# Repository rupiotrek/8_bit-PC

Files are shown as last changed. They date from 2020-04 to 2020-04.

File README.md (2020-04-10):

# 8_bit-PC

Project based on the project of [8 bit PC by Ben Eater](https://eater.net/8bit/ "8 bit by Ben Eater").  

# Version 1

Contains:
1. 3 board & schematic designs
2. Gerber files for production
3. BOM 

Board divided into 3 parts:

## Left

|Name of unit|Description|
| --- | ---|
|**Clock**|Creats clock signal for the board. Can be used also as debugger - clock signal can be made by user |
|**Memory address (MAR)**|Choose from which address PC reads. In *Prog*  mode user can specify address to which instructions in RAM module will be written |
|**RAM**| Contains instructions for specified memory address. In *Prog* mode user can specify instruction for chosen in MAR module addres |
|**Instruction register (IR)**| Decides which step of the program will be made next. It is sent to PC module. Also sends the address to read from  |
|**Control Word (CW)**| Operates whole PC. Also shows which flag is ON during working|

## Middle
|Name of unit|Description|
| ----- |-----|
|**Display module**|Shows current information on the bus |
|**Sorting module**|Unit transports signals from left and right board to specified unit|

## Right
|Name of unit|Description|
|-----|-----|
|**Program counter (PC)**|Makes steps for the PC. Can also change them because of *jump* function |
|**Power**| Main power unit. Contains overvoltage and reverse polarity protection |
|**A register**|Register that can read from and write informations for the bus. Contains information on which computer is working recently |
|**Arithmetic Logic Unit (ALU)**| Mathematical unit. Operates on variables from A and B registers. Module can add and substruct them |
|**B register**|Register that can read informations from the bus. Contains information on which computer is working recently  |
|**Output register**| Show the variable on 4 display LED. Unit has two modes: non-neagtive and negative  |

# Links

This materials were really helpful during creation:

+ [Tutorial how to build the 8 bit PC](https://www.youtube.com/watch?v=HyznrdDSSGM&list=PLowKtXNTBypGqImE405J2565dvjafglHU)
+ [Ben Eater project site](https://eater.net/8bit/ )
+ [Helpful list of 74ls series ](https://www.futurlec.com/IC74LS00Series.shtml)

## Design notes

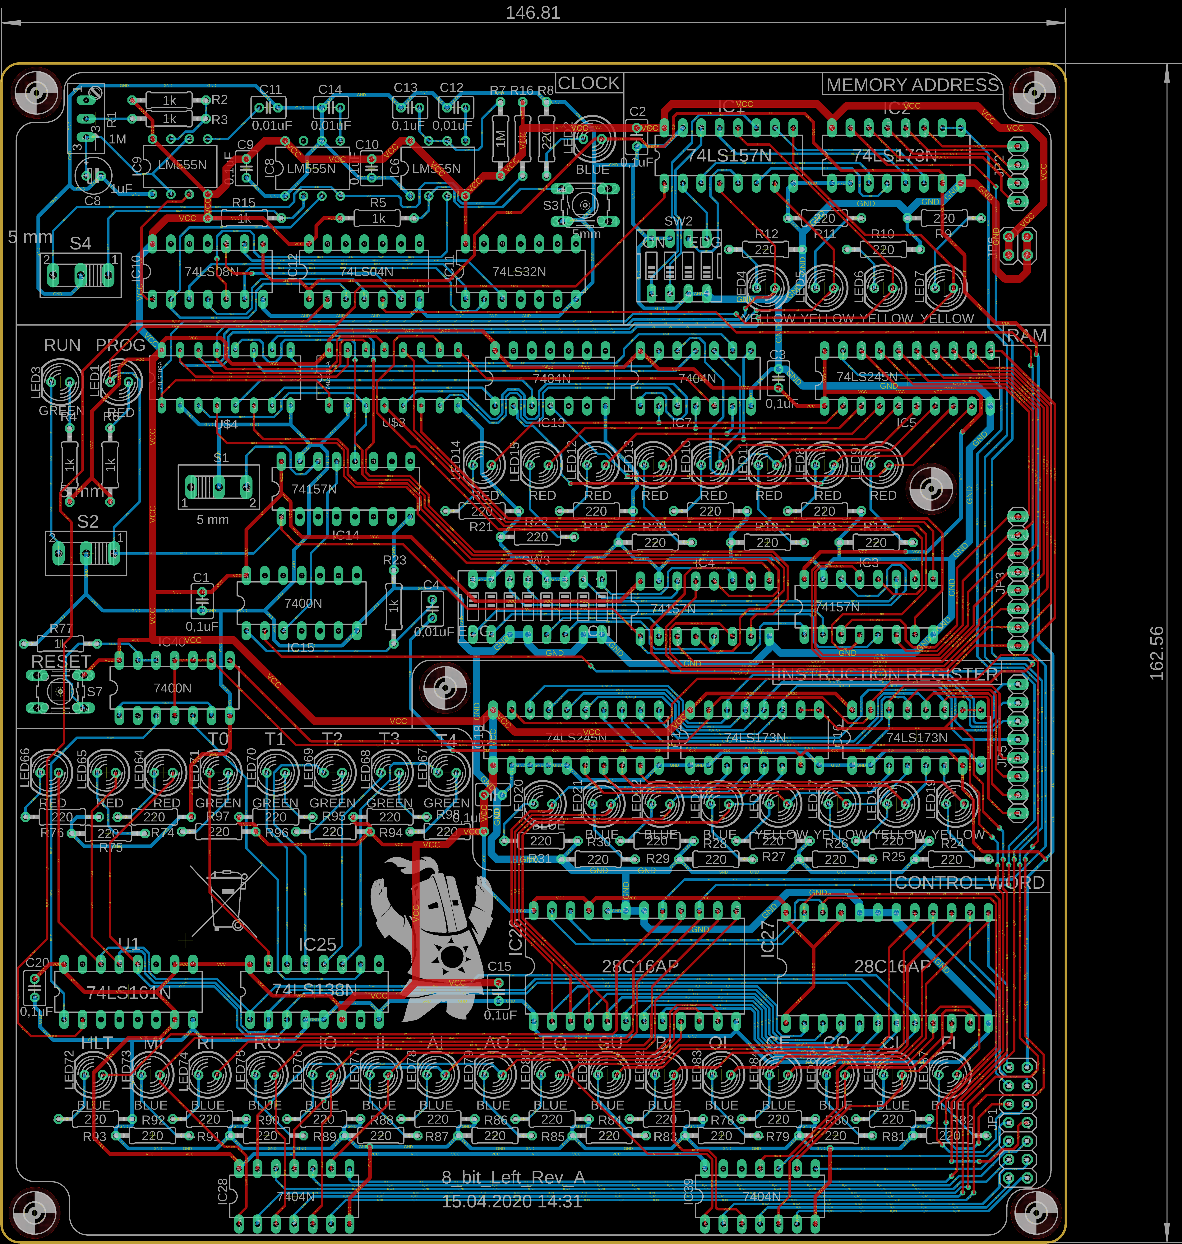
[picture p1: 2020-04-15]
Version_1/Screen_Left.png

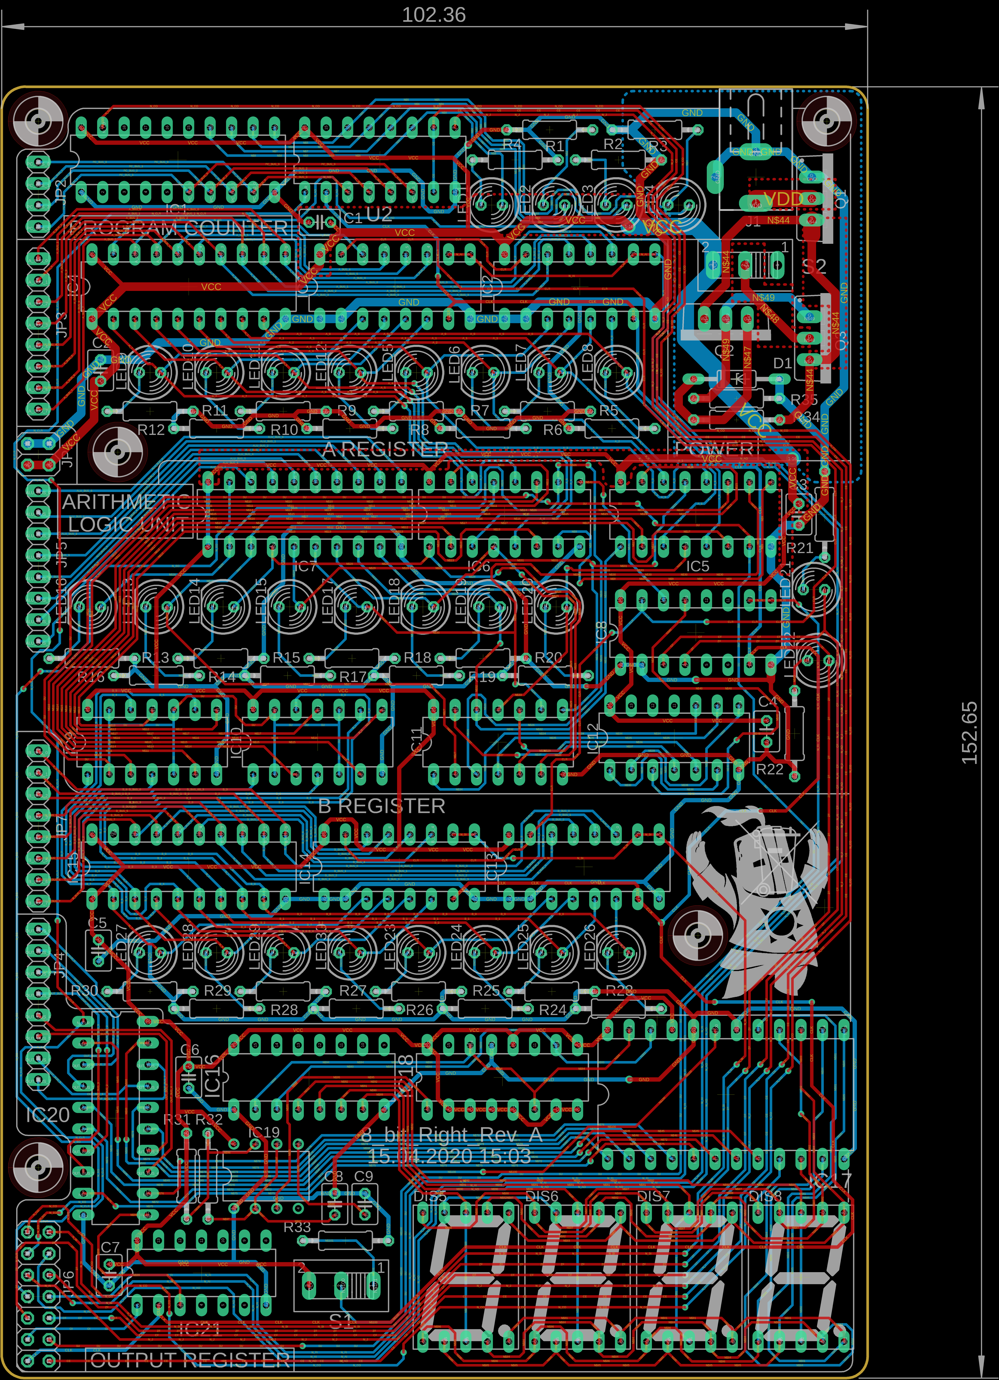
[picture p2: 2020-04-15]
Version_1/Screen_Right.png

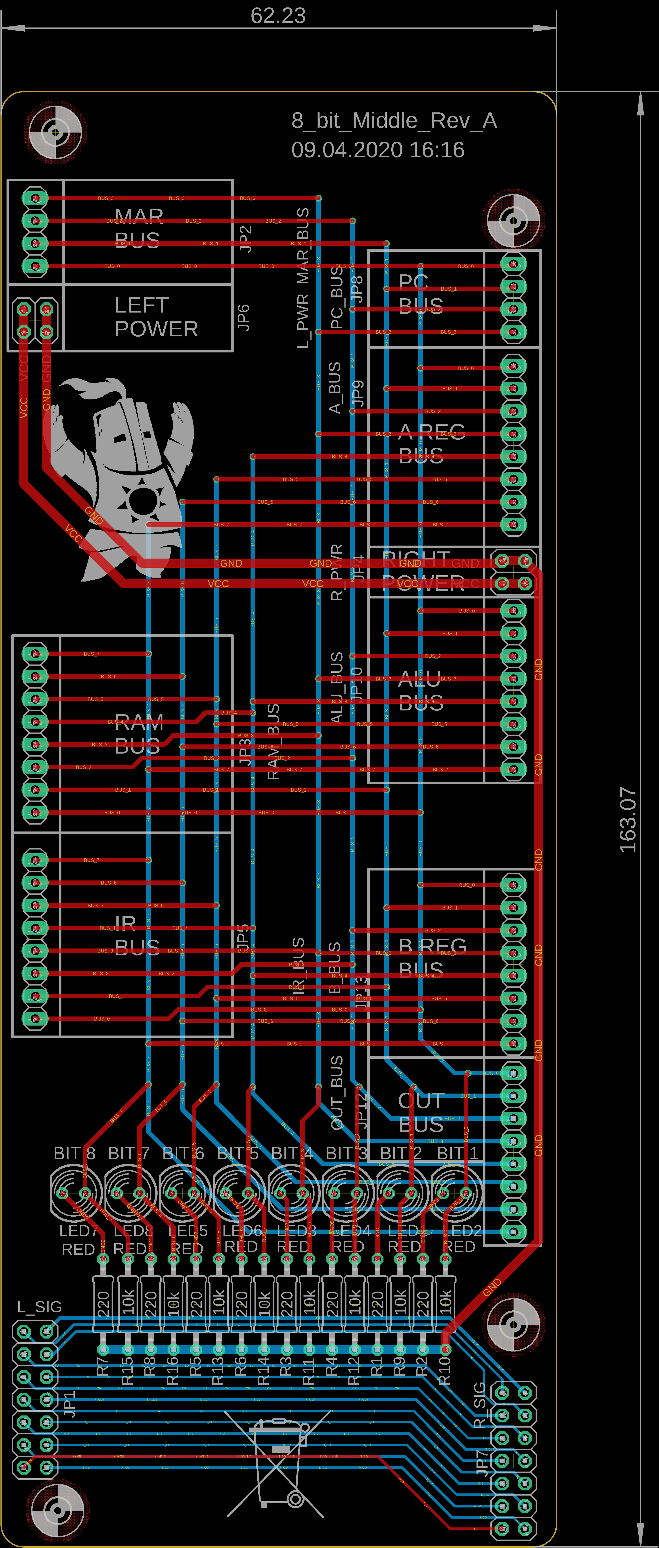
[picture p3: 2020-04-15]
Version_1/Screen_Middle.png

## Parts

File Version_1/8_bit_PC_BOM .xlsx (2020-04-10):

Qty | Value | Device | PCB | Package | Parts | Description | MF | MPN | OC_FARNELL | OC_NEWARK | POPULARITY | R9 | SPICEPREFIX
1 | 5mm | 10-XX | Left | B3F-10XX | S3 | OMRON SWITCH |  | B3F-1000 | 176432 | 36M3542 | 72
1 | RESET | 10-XX | Left | B3F-10XX | S7 | OMRON SWITCH |  | B3F-1000 | 176432 | 36M3542 | 72
3 | 5 mm | 255SB | Left | 255SB | S1, S2, S4 | SLIDING SWITCH |  |  |  |  | 11
1 |  | 255SB | Right | 255SB | S2 | SLIDING SWITCH |  |  |  |  | 11
1 | 5 mm | 255SB | Right | 255SB | S1 | SLIDING SWITCH |  |  |  |  | 11
2 | 28C16AP | 28C16AP | Left | DIL24-6 | IC26, IC27 | CMOS EPROM 16 K (2 K x 8) |  | CAT28C16ALI-12 | 1718292 | 06R0648
1 | 28C16AP | 28C16AP | Right | DIL24-6 | IC17 | CMOS EPROM 16 K (2 K x 8) |  | CAT28C16ALI-12 | 1718292 | 06R0648
2 | 74LS00N | 74LS00N | Left | DIL14 | IC15, IC40 | Quad 2-input NAND gate |  |  |  |  | 0
1 | 74LS02N | 74LS02N | Right | DIL14 | IC11 | Quad 2-input NOR gate |  |  |  |  | 0
4 | 74LS04N | 74LS04N | Left | DIL14 | IC7, IC13, IC28, IC39 | Hex INVERTER |  |  |  |  | 0
1 | 74LS04N | 74LS04N | Left | DIL14 | IC12 | Hex INVERTER |  |  |  |  | 0
1 | 74LS08N | 74LS08N | Left | DIL14 | IC10 | Quad 2-input AND gate |  |  |  |  | 0
1 | 74LS08N | 74LS08N | Right | DIL14 | IC21 | Quad 2-input AND gate
1 | 74LS08N | 74LS08N | Right | DIL14 | IC12 | Quad 2-input AND gate |  |  |  |  | 0
1 | 74LS138N | 74LS138N | Left | DIL16 | IC25 | 3-line to 8-line DECODER/DEMULTIPLEXER
1 | 74LS139N | 74LS139N | Right | DIL16 | IC16 | Dual 2-line to 4-line DECODER/DEMULTIPLEXER
3 | 74LS157N | 74LS157N | Left | DIL16 | IC3, IC4, IC14 | Quadruple 2-line to 1-line data SELECTOR/MULTIPLEXER |  |  |  |  | 0
1 | 74LS157N | 74LS157N | Left | DIL16 | IC1 | Quadruple 2-line to 1-line data SELECTOR/MULTIPLEXER
1 | 74LS161N | 74LS161N | Left | DIL16 | U1 | Synchronous 4-bit COUNTER with direct clear
1 | 74LS161N | 74LS161N | Right | DIL16 | U2 | Synchronous 4-bit COUNTER with direct clear
2 | 74LS173N | 74LS173N | Left | DIL16 | IC16, IC17 | 4-bit D type REGISTER, 3-state |  |  |  |  | 0
1 | 74LS173N | 74LS173N | Left | DIL16 | IC2 | 4-bit D type REGISTER, 3-state
5 | 74LS173N | 74LS173N | Right | DIL16 | IC2, IC3, IC8, IC13, IC14 | 4-bit D type REGISTER, 3-state |  |  |  |  | 0
2 | 74LS189A | 74LS189A | Left | 74LS189 | U$3, U$4
2 | 74LS245N | 74LS245N | Left | DIL20 | IC5, IC18 | Octal BUS TRANSCEIVER, 3-state |  |  |  |  | 0
4 | 74LS245N | 74LS245N | Right | DIL20 | IC1, IC4, IC7, IC15 | Octal BUS TRANSCEIVER, 3-state |  |  |  |  | 0
1 | 74LS273N | 74LS273N | Right | DIL20 | IC20 | Octal D type FLIP FLOP, clear
1 | 74LS32N | 74LS32N | Left | DIL14 | IC11 | Quad 2-input OR gate |  |  |  |  | 0
1 | 74LS76N | 74LS76N | Right | DIL16 | IC18 | Dual J-K FLIP FLOP, preset and clear
2 | 74LS86N | 74LS86N | Right | DIL14 | IC9, IC10 | Quad 2-input EXCLUSIVE-OR (XOR) gate |  |  |  |  | 0
2 | 74S283N | 74S283N | Right | DIL16 | IC5, IC6 | 4-bit binary FULL ADDER, fast carry |  |  |  |  | 0
1 | BZX55 | BZX55 | Right | DO35Z10 | D1 | Z DIODE |  |  |  |  | 2
4 | 0,01uF | C-EU025-030X050 | Left | C025-030X050 | C4, C11, C12, C14 | CAPACITOR, European symbol |  |  |  |  |  |  | C
9 | 0,1uF | C-EU025-030X050 | Left | C025-030X050 | C1, C2, C3, C5, C9, C10, C13, C15, C20 | CAPACITOR, European symbol |  |  |  |  |  |  | C
2 | 0,01uF | C-EU025-030X050 | Right | C025-030X050 | C8, C9 | CAPACITOR, European symbol |  |  |  |  |  |  | C
7 | 0,1uF | C-EU025-030X050 | Right | C025-030X050 | C1, C2, C3, C4, C5, C6, C7 | CAPACITOR, European symbol |  |  |  |  |  |  | C
1 | 1uF | CPOL-EUE2-5 | Left | E2-5 | C8 | POLARIZED CAPACITOR, European symbol |  |  |  |  |  |  | C
1 |  | DCJ0303 | Right | DCJ0303 | J1 | DC POWER JACK |  |  | unknown | unknown | 20
4 | HD-H103 | HD-H103 | Right | HDSP-M | DIS5, DIS6, DIS7, DIS8 | LED DISPLAY |  |  | unknown | unknown
3 | IRF9530 | IRF9530 | Right | TO220BV | Q1, Q2, Q3 | P-CHANNEL HEXFET POWER-MOS-FET |  |  |  |  | 4
21 | BLUE | LED5MM | Left | LED5MM | LED2, LED20, LED21, LED22, LED23, LED72, LED73, LED74, LED75, LED76, LED77, LED78, LED79, LED80, LED81, LED82, LED83, LED84, LED85, LED86, LED87 | LED
6 | GREEN | LED5MM | Left | LED5MM | LED3, LED67, LED68, LED69, LED70, LED71 | LED
12 | RED | LED5MM | Left | LED5MM | LED1, LED8, LED9, LED10, LED11, LED12, LED13, LED14, LED15, LED64, LED65, LED66 | LED
8 | YELLOW | LED5MM | Left | LED5MM | LED4, LED5, LED6, LED7, LED16, LED17, LED18, LED19 | LED
8 | RED | LED5MM | Middle | LED5MM | LED1, LED2, LED3, LED4, LED5, LED6, LED7, LED8 | LED
6 | GREEN | LED5MM | Right | LED5MM | LED1, LED2, LED3, LED4, LED21, LED22 | LED
24 | RED | LED5MM | Right | LED5MM | LED5, LED6, LED7, LED8, LED9, LED10, LED11, LED12, LED13, LED14, LED15, LED16, LED17, LED18, LED19, LED20, LED23, LED24, LED25, LED26, LED27, LED28, LED29, LED30 | LED
3 | LM555N | LM555N | Left | DIL08 | IC6, IC8, IC9 | TIMER
1 | LM555N | LM555N | Right | DIL08 | IC19 | TIMER
4 | MOUNT-HOLE2.8 | MOUNT-HOLE2.8 | Middle | 2.8 | H1, H2, H3, H4 | MOUNTING HOLE with drill center marker |  |  |  |  | 15
5 | MOUNT-HOLE2.8 | MOUNT-HOLE2.8 | Right | 2.8 | H1, H2, H3, H5, H6 | MOUNTING HOLE with drill center marker |  |  |  |  | 15
1 |  | PINHD-1X4 | Left | 1X04 | JP2 | PIN HEADER |  |  |  |  | 91
1 | MAR_BUS | PINHD-1X4 | Middle | 1X04 | JP2 | PIN HEADER |  |  |  |  | 91
1 | PC_BUS | PINHD-1X4 | Middle | 1X04 | JP8 | PIN HEADER |  |  |  |  | 91
1 |  | PINHD-1X4 | Right | 1X04 | JP2 | PIN HEADER |  |  |  |  | 91
2 |  | PINHD-1X8 | Left | 1X08 | JP3, JP5 | PIN HEADER |  |  |  |  | 67
1 | ALU_BUS | PINHD-1X8 | Middle | 1X08 | JP10 | PIN HEADER |  |  |  |  | 67
1 | A_BUS | PINHD-1X8 | Middle | 1X08 | JP9 | PIN HEADER |  |  |  |  | 67
1 | B_BUS | PINHD-1X8 | Middle | 1X08 | JP13 | PIN HEADER |  |  |  |  | 67
1 | IR_BUS | PINHD-1X8 | Middle | 1X08 | JP5 | PIN HEADER |  |  |  |  | 67
1 | OUT_BUS | PINHD-1X8 | Middle | 1X08 | JP12 | PIN HEADER |  |  |  |  | 67
1 | RAM_BUS | PINHD-1X8 | Middle | 1X08 | JP3 | PIN HEADER |  |  |  |  | 67
4 |  | PINHD-1X8 | Right | 1X08 | JP3, JP4, JP5, JP7 | PIN HEADER |  |  |  |  | 67
1 |  | PINHD-2X2 | Left | 2X02 | JP6 | PIN HEADER |  |  |  |  | 0
1 | L_PWR | PINHD-2X2 | Middle | 2X02 | JP6 | PIN HEADER |  |  |  |  | 0
1 | R_PWR | PINHD-2X2 | Middle | 2X02 | JP4 | PIN HEADER |  |  |  |  | 0
1 |  | PINHD-2X2 | Right | 2X02 | JP1 | PIN HEADER |  |  |  |  | 0
1 |  | PINHD-2X7 | Left | 2X07 | JP1 | PIN HEADER |  |  |  |  | 8
1 | L_SIG | PINHD-2X7 | Middle | 2X07 | JP1 | PIN HEADER |  |  |  |  | 8
1 | R_SIG | PINHD-2X7 | Middle | 2X07 | JP7 | PIN HEADER |  |  |  |  | 8
1 |  | PINHD-2X7 | Right | 2X07 | JP6 | PIN HEADER |  |  |  |  | 8
1 | 1M | POTTRS64W | Left | S64W | R1 | POTENTIOMETER |  |  |  |  |  | 1M
1 | 1M | R-EU_0207/10 | Left | 0207/10 | R7 | RESISTOR, European symbol |  |  |  |  | 81 |  | R
9 | 1k | R-EU_0207/10 | Left | 0207/10 | R2, R3, R4, R5, R6, R8, R15, R23, R77 | RESISTOR, European symbol |  |  |  |  | 81 |  | R
45 | 220 | R-EU_0207/10 | Left | 0207/10 | R9, R10, R11, R12, R13, R14, R16, R17, R18, R19, R20, R21, R22, R24, R25, R26, R27, R28, R29, R30, R31, R74, R75, R76, R78, R79, R80, R81, R82, R83, R84, R85, R86, R87, R88, R89, R90, R91, R92, R93, R94, R95, R96, R97, R98 | RESISTOR, European symbol |  |  |  |  | 81 |  | R
8 | 10k | R-EU_0207/10 | Middle | 0207/10 | R9, R10, R11, R12, R13, R14, R15, R16 | RESISTOR, European symbol |  |  |  |  | 81 |  | R
8 | 220 | R-EU_0207/10 | Middle | 0207/10 | R1, R2, R3, R4, R5, R6, R7, R8 | RESISTOR, European symbol |  |  |  |  | 81 |  | R
1 | 100k | R-EU_0207/10 | Right | 0207/10 | R32 | RESISTOR, European symbol |  |  |  |  | 81 |  | R
1 | 10k | R-EU_0207/10 | Right | 0207/10 | R33 | RESISTOR, European symbol |  |  |  |  | 81 |  | R
2 | 1k | R-EU_0207/10 | Right | 0207/10 | R31, R35 | RESISTOR, European symbol |  |  |  |  | 81 |  | R
31 | 220 | R-EU_0207/10 | Right | 0207/10 | R1, R2, R3, R4, R5, R6, R7, R8, R9, R10, R11, R12, R13, R14, R15, R16, R17, R18, R19, R20, R21, R22, R23, R24, R25, R26, R27, R28, R29, R30, R34 | RESISTOR, European symbol |  |  |  |  | 81 |  | R
1 |  | SW_DIP-4 | Left | EDG-04 | SW2 | DIP SWITCH
1 |  | SW_DIP-8 | Left | EDG-08 | SW3 | DIP SWITCH |  |  |  |  | 5

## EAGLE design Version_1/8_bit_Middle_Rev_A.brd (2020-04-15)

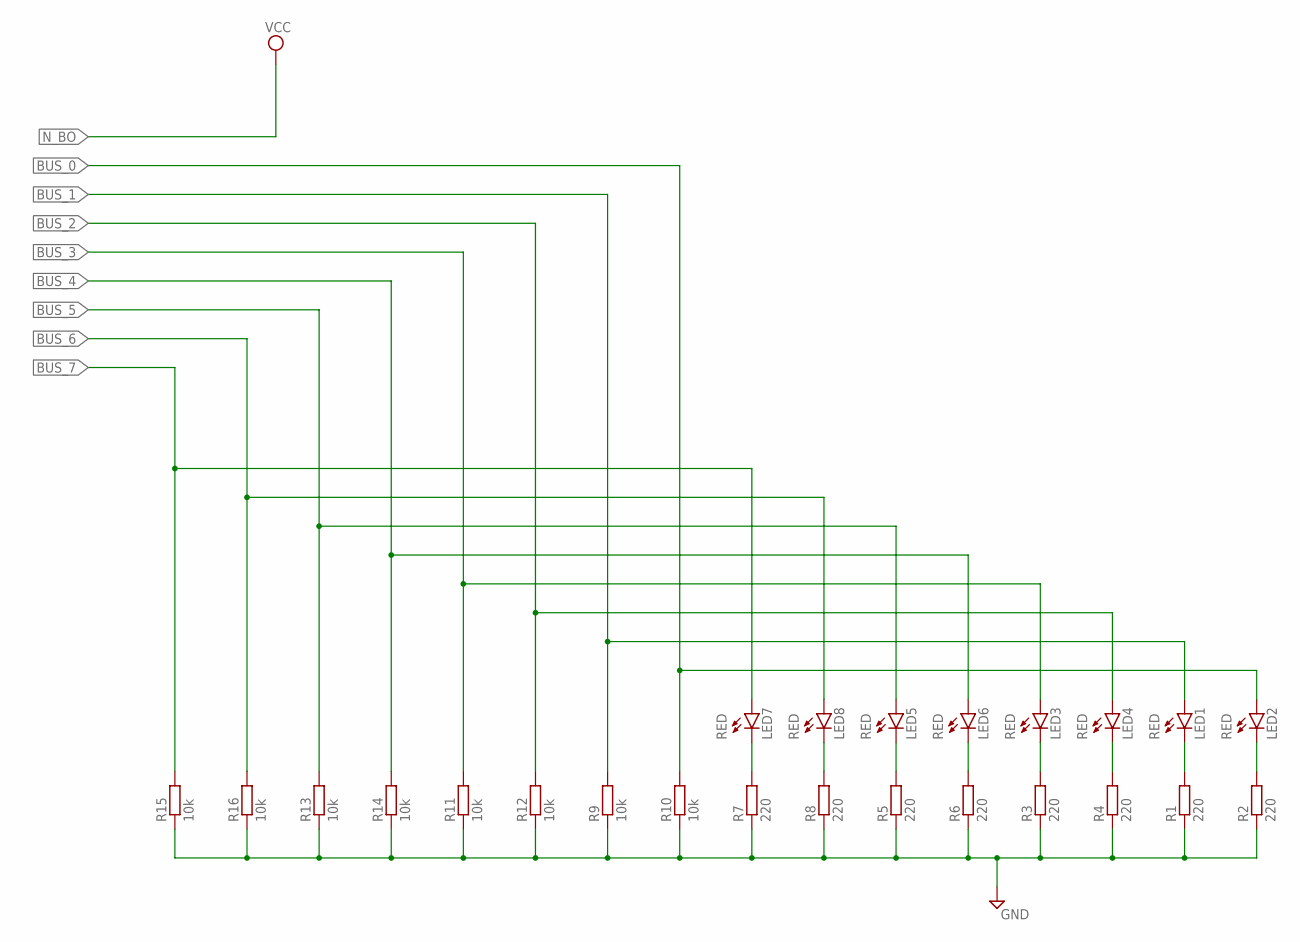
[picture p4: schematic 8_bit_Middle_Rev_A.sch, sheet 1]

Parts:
LED1, LED2, LED3, LED4, LED5, LED6, LED7, LED8: RED; LED5MM
R1, R2, R3, R4, R5, R6, R7, R8: 220; 0207/10
R9, R10, R11, R12, R13, R14, R15, R16: 10k; 0207/10

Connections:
BUS_0: LED2.A, R10.2; also elsewhere on the board
BUS_1: LED1.A, R9.2; also elsewhere on the board
BUS_2: LED4.A, R12.2; also elsewhere on the board
BUS_3: LED3.A, R11.2; also elsewhere on the board
BUS_4: LED6.A, R14.2; also elsewhere on the board
BUS_5: LED5.A, R13.2; also elsewhere on the board
BUS_6: LED8.A, R16.2; also elsewhere on the board
BUS_7: LED7.A, R15.2; also elsewhere on the board
GND: R1.1, R2.1, R3.1, R4.1, R5.1, R6.1, R7.1, R8.1, R9.1, R10.1, R11.1, R12.1, R13.1, R14.1, R15.1, R16.1; also elsewhere on the board
GND1: LED1.K (C), R1.2
GND2: LED2.K (C), R2.2
GND3: LED3.K (C), R3.2
GND5: LED4.K (C), R4.2
GND7: LED5.K (C), R5.2
GND8: LED6.K (C), R6.2
GND9: LED7.K (C), R7.2
GND10: LED8.K (C), R8.2

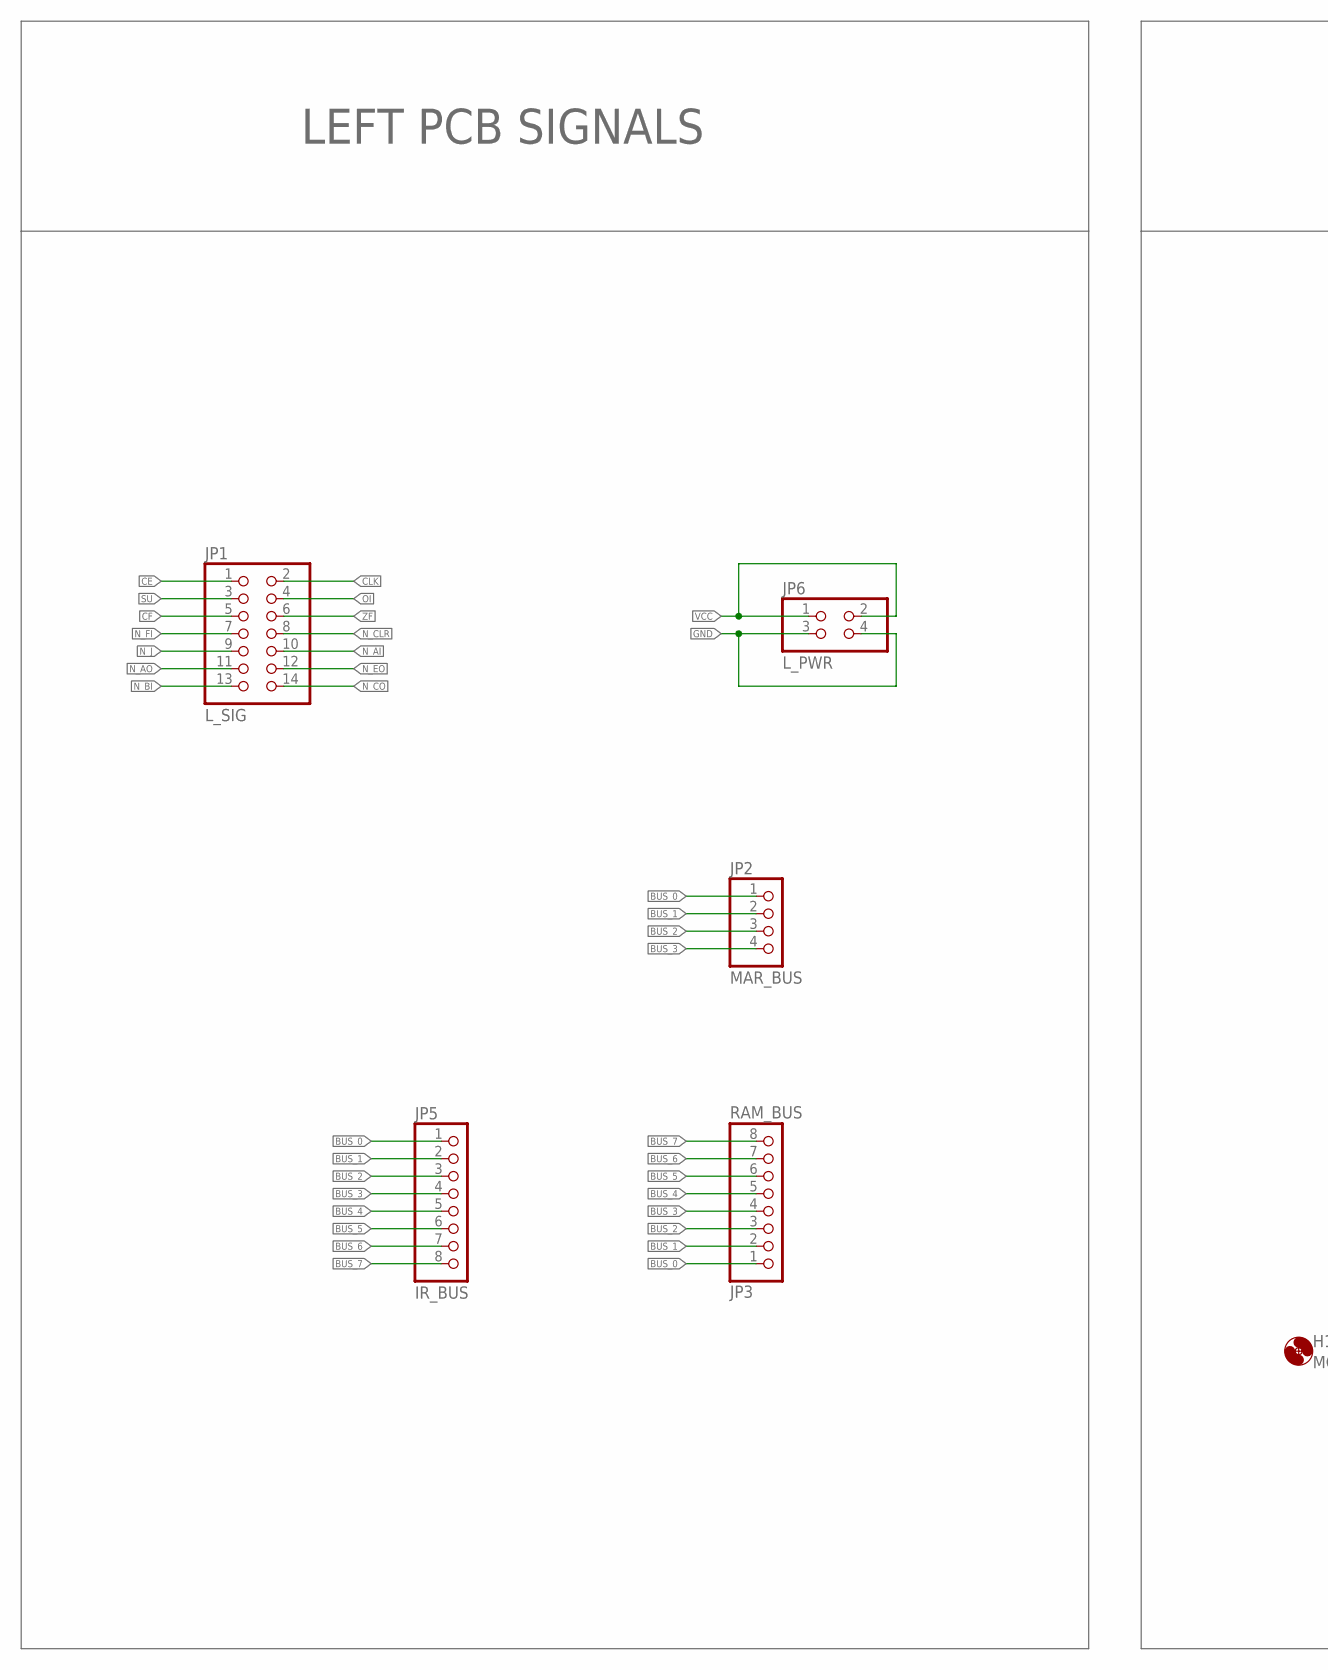
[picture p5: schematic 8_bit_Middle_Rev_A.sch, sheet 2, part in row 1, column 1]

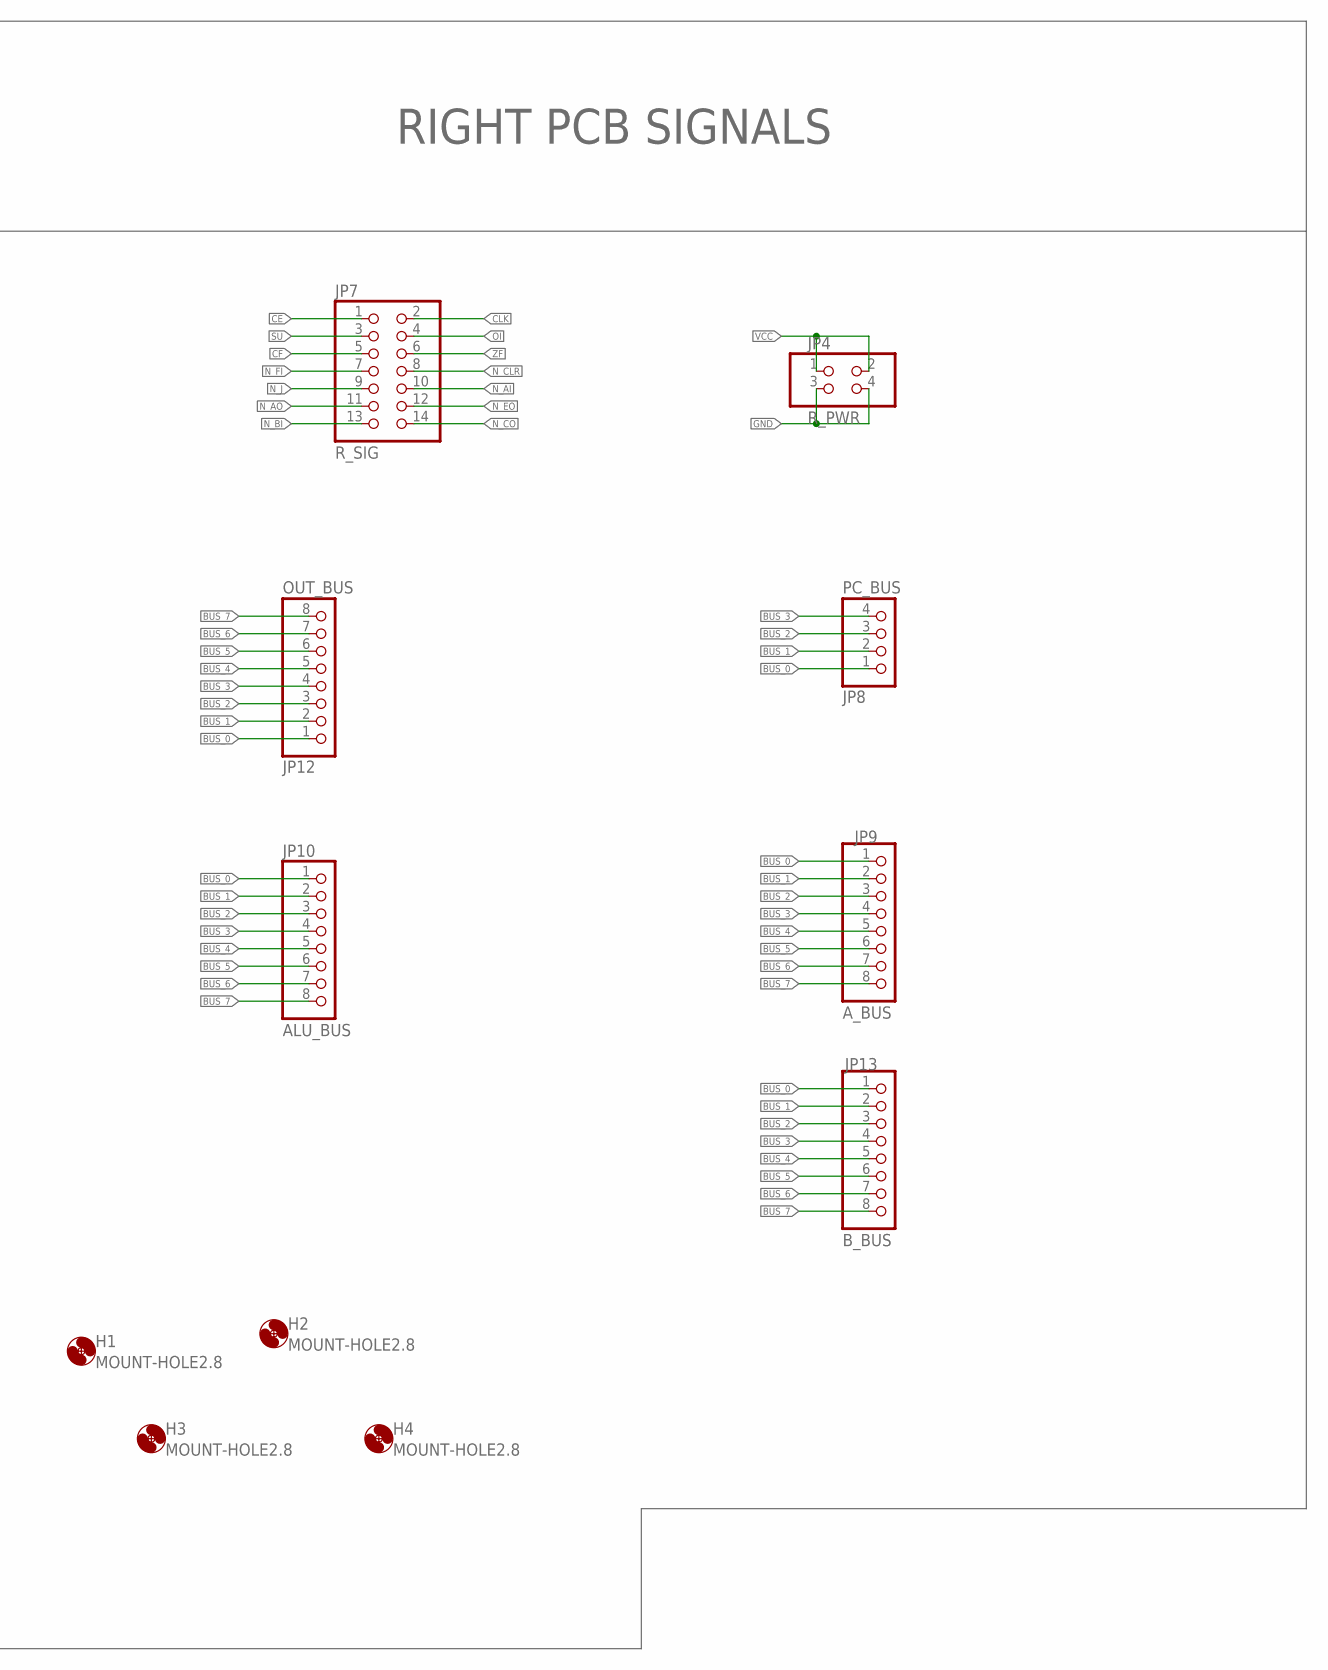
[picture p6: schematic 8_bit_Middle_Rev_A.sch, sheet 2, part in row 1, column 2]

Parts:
H1, H2, H3, H4: MOUNT-HOLE2.8; 2,8
JP1: L_SIG; 2X07
JP2: MAR_BUS; 1X04
JP3: RAM_BUS; 1X08
JP4: R_PWR; 2X02
JP5: IR_BUS; 1X08
JP6: L_PWR; 2X02
JP7: R_SIG; 2X07
JP8: PC_BUS; 1X04
JP9: A_BUS; 1X08
JP10: ALU_BUS; 1X08
JP12: OUT_BUS; 1X08
JP13: B_BUS; 1X08

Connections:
BUS_0: JP2.1, JP3.1, JP5.1, JP8.1, JP9.1, JP10.1, JP12.1, JP13.1; also elsewhere on the board
BUS_1: JP2.2, JP3.2, JP5.2, JP8.2, JP9.2, JP10.2, JP12.2, JP13.2; also elsewhere on the board
BUS_2: JP2.3, JP3.3, JP5.3, JP8.3, JP9.3, JP10.3, JP12.3, JP13.3; also elsewhere on the board
BUS_3: JP2.4, JP3.4, JP5.4, JP8.4, JP9.4, JP10.4, JP12.4, JP13.4; also elsewhere on the board
BUS_4: JP3.5, JP5.5, JP9.5, JP10.5, JP12.5, JP13.5; also elsewhere on the board
BUS_5: JP3.6, JP5.6, JP9.6, JP10.6, JP12.6, JP13.6; also elsewhere on the board
BUS_6: JP3.7, JP5.7, JP9.7, JP10.7, JP12.7, JP13.7; also elsewhere on the board
BUS_7: JP3.8, JP5.8, JP9.8, JP10.8, JP12.8, JP13.8; also elsewhere on the board
CE: JP1.1, JP7.1
CF: JP1.5, JP7.5
CLK: JP1.2, JP7.2
GND: JP4.3, JP4.4, JP6.3, JP6.4; also elsewhere on the board
N_AI: JP1.10, JP7.10
N_AO: JP1.11, JP7.11
N_BI: JP1.13, JP7.13
N_CLR: JP1.8, JP7.8
N_CO: JP1.14, JP7.14
N_EO: JP1.12, JP7.12
N_FI: JP1.7, JP7.7
N_J: JP1.9, JP7.9
OI: JP1.4, JP7.4
SU: JP1.3, JP7.3
VCC: JP4.1, JP4.2, JP6.1, JP6.2
ZF: JP1.6, JP7.6

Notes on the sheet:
LEFT PCB SIGNALS
RIGHT PCB SIGNALS

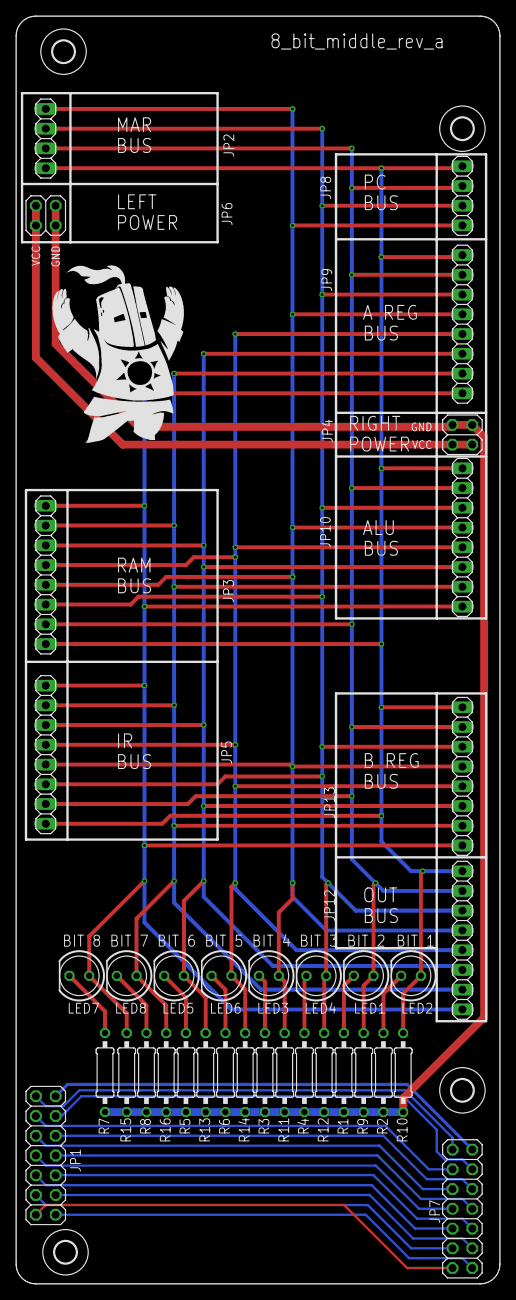
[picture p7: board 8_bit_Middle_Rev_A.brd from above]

Board: 2 copper layers, 62.2 x 163.1 mm, 42 parts (1 on the bottom side), 32 nets.

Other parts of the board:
U$1: SOLAIRE
U$2: MUELLTONNE

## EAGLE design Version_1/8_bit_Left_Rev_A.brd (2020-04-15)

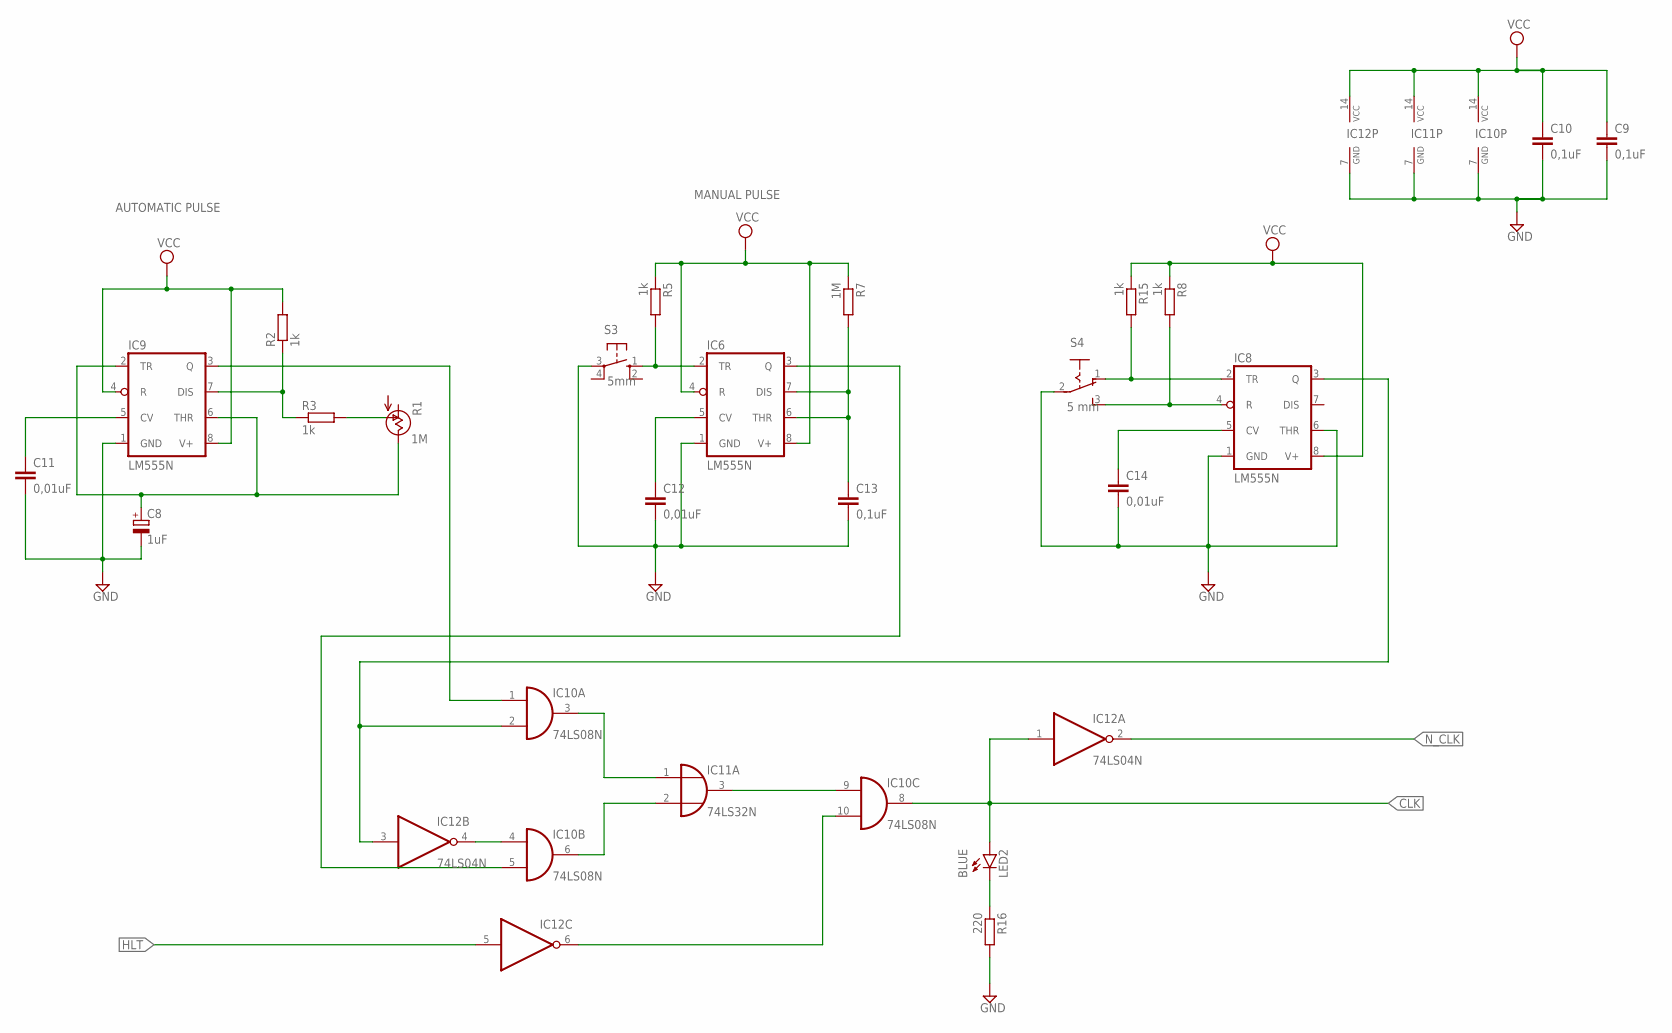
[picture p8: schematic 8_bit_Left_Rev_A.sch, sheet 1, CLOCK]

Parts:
C8: 1uF; E2-5
C9, C10, C13: 0,1uF; C025-030X050
C11, C12, C14: 0,01uF; C025-030X050
IC6, IC8, IC9: LM555N; DIL08
IC10: 74LS08N; DIL14
IC11: 74LS32N; DIL14
IC12: 74LS04N; DIL14
LED2: BLUE; LED5MM
R1: 1M; S64W
R2, R3, R5, R8, R15: 1k; 0207/10
R7: 1M; 0207/10
R16: 220; 0207/10
S3: 5mm; B3F-10XX
S4: 5 mm; 255SB

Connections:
CLK: IC10.8 (O), IC12.1 (I), LED2.A; also elsewhere on the board
GND: C8.-, C9.2, C10.2, C11.2, C12.2, C13.2, C14.2, IC6.1 (GND), IC8.1 (GND), IC8.6 (THR), IC9.1 (GND), IC10.7 (GND), IC11.7 (GND), IC12.7 (GND), R16.2, S3.3, S4.2; also elsewhere on the board
HLT: IC12.5 (I); also elsewhere on the board
unnamed: IC9.7 (DIS), R2.1, R3.1
unnamed: C8.+, IC9.2 (TR), IC9.6 (THR), R1.E (VSS)
unnamed: C11.1, IC9.5 (CV)
unnamed: C12.1, IC6.5 (CV)
unnamed: C13.1, IC6.6 (THR), IC6.7 (DIS), R7.2
unnamed: IC6.2 (TR), R5.2, S3.1 (S)
unnamed: IC8.4 (R), R8.2, S4.3 (S)
unnamed: IC8.2 (TR), R15.2, S4.1 (O)
unnamed: C14.1, IC8.5 (CV)
unnamed: IC9.3 (Q), IC10.1 (I0)
unnamed: IC6.3 (Q), IC10.5 (I1)
unnamed: IC10.4 (I0), IC12.4 (O)
unnamed: IC8.3 (Q), IC10.2 (I1), IC12.3 (I)
unnamed: IC10.3 (O), IC11.1 (I0)
unnamed: IC10.6 (O), IC11.2 (I1)
unnamed: IC10.9 (I0), IC11.3 (O)
unnamed: IC10.10 (I1), IC12.6 (O)
unnamed: R1.S (OUT), R3.2
unnamed: LED2.K (C), R16.1
N_CLK: IC12.2 (O); also elsewhere on the board
VCC: C9.1, C10.1, IC6.4 (R), IC6.8 (V+), IC8.8 (V+), IC9.4 (R), IC9.8 (V+), IC10.14 (VCC), IC11.14 (VCC), IC12.14 (VCC), R2.2, R5.1, R7.1, R8.1, R15.1; also elsewhere on the board

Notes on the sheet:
MANUAL PULSE
AUTOMATIC PULSE

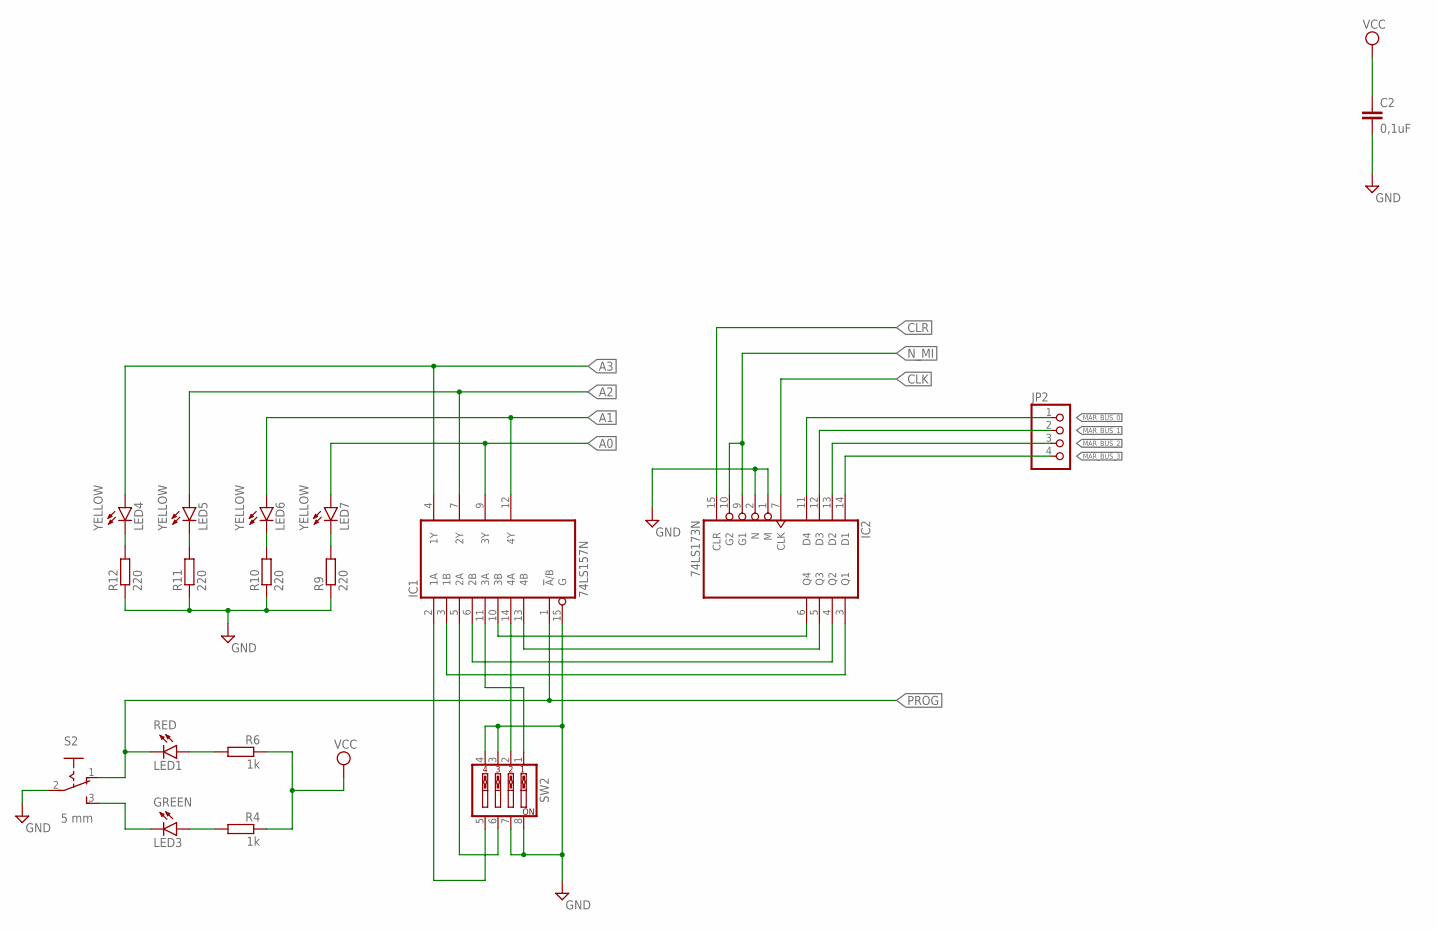
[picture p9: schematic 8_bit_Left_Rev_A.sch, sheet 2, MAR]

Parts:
C2: 0,1uF; C025-030X050
IC1: 74LS157N; DIL16
IC2: 74LS173N; DIL16
JP2: PINHD-1X4; 1X04
LED1: RED; LED5MM
LED3: GREEN; LED5MM
LED4, LED5, LED6, LED7: YELLOW; LED5MM
R4, R6: 1k; 0207/10
R9, R10, R11, R12: 220; 0207/10
S2: 5 mm; 255SB
SW2: EDG-04

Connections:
A0: IC1.9 (3Y), LED7.A; also elsewhere on the board
A1: IC1.12 (4Y), LED6.A; also elsewhere on the board
A2: IC1.7 (2Y), LED5.A; also elsewhere on the board
A3: IC1.4 (1Y), LED4.A; also elsewhere on the board
CLK: IC2.7 (CLK); also elsewhere on the board
CLR: IC2.15 (CLR); also elsewhere on the board
GND: C2.2, IC1.8 (GND), IC1.15 (G), IC2.1 (M), IC2.2 (N), IC2.8 (GND), R9.1, R10.1, R11.1, R12.1, S2.2, SW2.3, SW2.4, SW2.7, SW2.8; also elsewhere on the board
GND1: LED7.K (C), R9.2
GND2: LED6.K (C), R10.2
GND3: LED5.K (C), R11.2
GND4: LED4.K (C), R12.2
MAR_BUS_0: IC2.11 (D4), JP2.1
MAR_BUS_1: IC2.12 (D3), JP2.2
MAR_BUS_2: IC2.13 (D2), JP2.3
MAR_BUS_3: IC2.14 (D1), JP2.4
unnamed: LED1.A, R6.2
unnamed: LED3.A, R4.2
unnamed: LED3.K (C), S2.3 (S)
unnamed: IC1.14 (4A), SW2.2
unnamed: IC1.11 (3A), SW2.1
unnamed: IC1.10 (3B), IC2.6 (Q4)
unnamed: IC1.13 (4B), IC2.5 (Q3)
unnamed: IC1.6 (2B), IC2.4 (Q2)
unnamed: IC1.3 (1B), IC2.3 (Q1)
unnamed: IC1.5 (2A), SW2.6
unnamed: IC1.2 (1A), SW2.5
N_MI: IC2.9 (G1), IC2.10 (G2); also elsewhere on the board
PROG: IC1.1 (!A!/B), LED1.K (C), S2.1 (O); also elsewhere on the board
VCC: C2.1, IC1.16 (VCC), IC2.16 (VCC), R4.1, R6.1; also elsewhere on the board

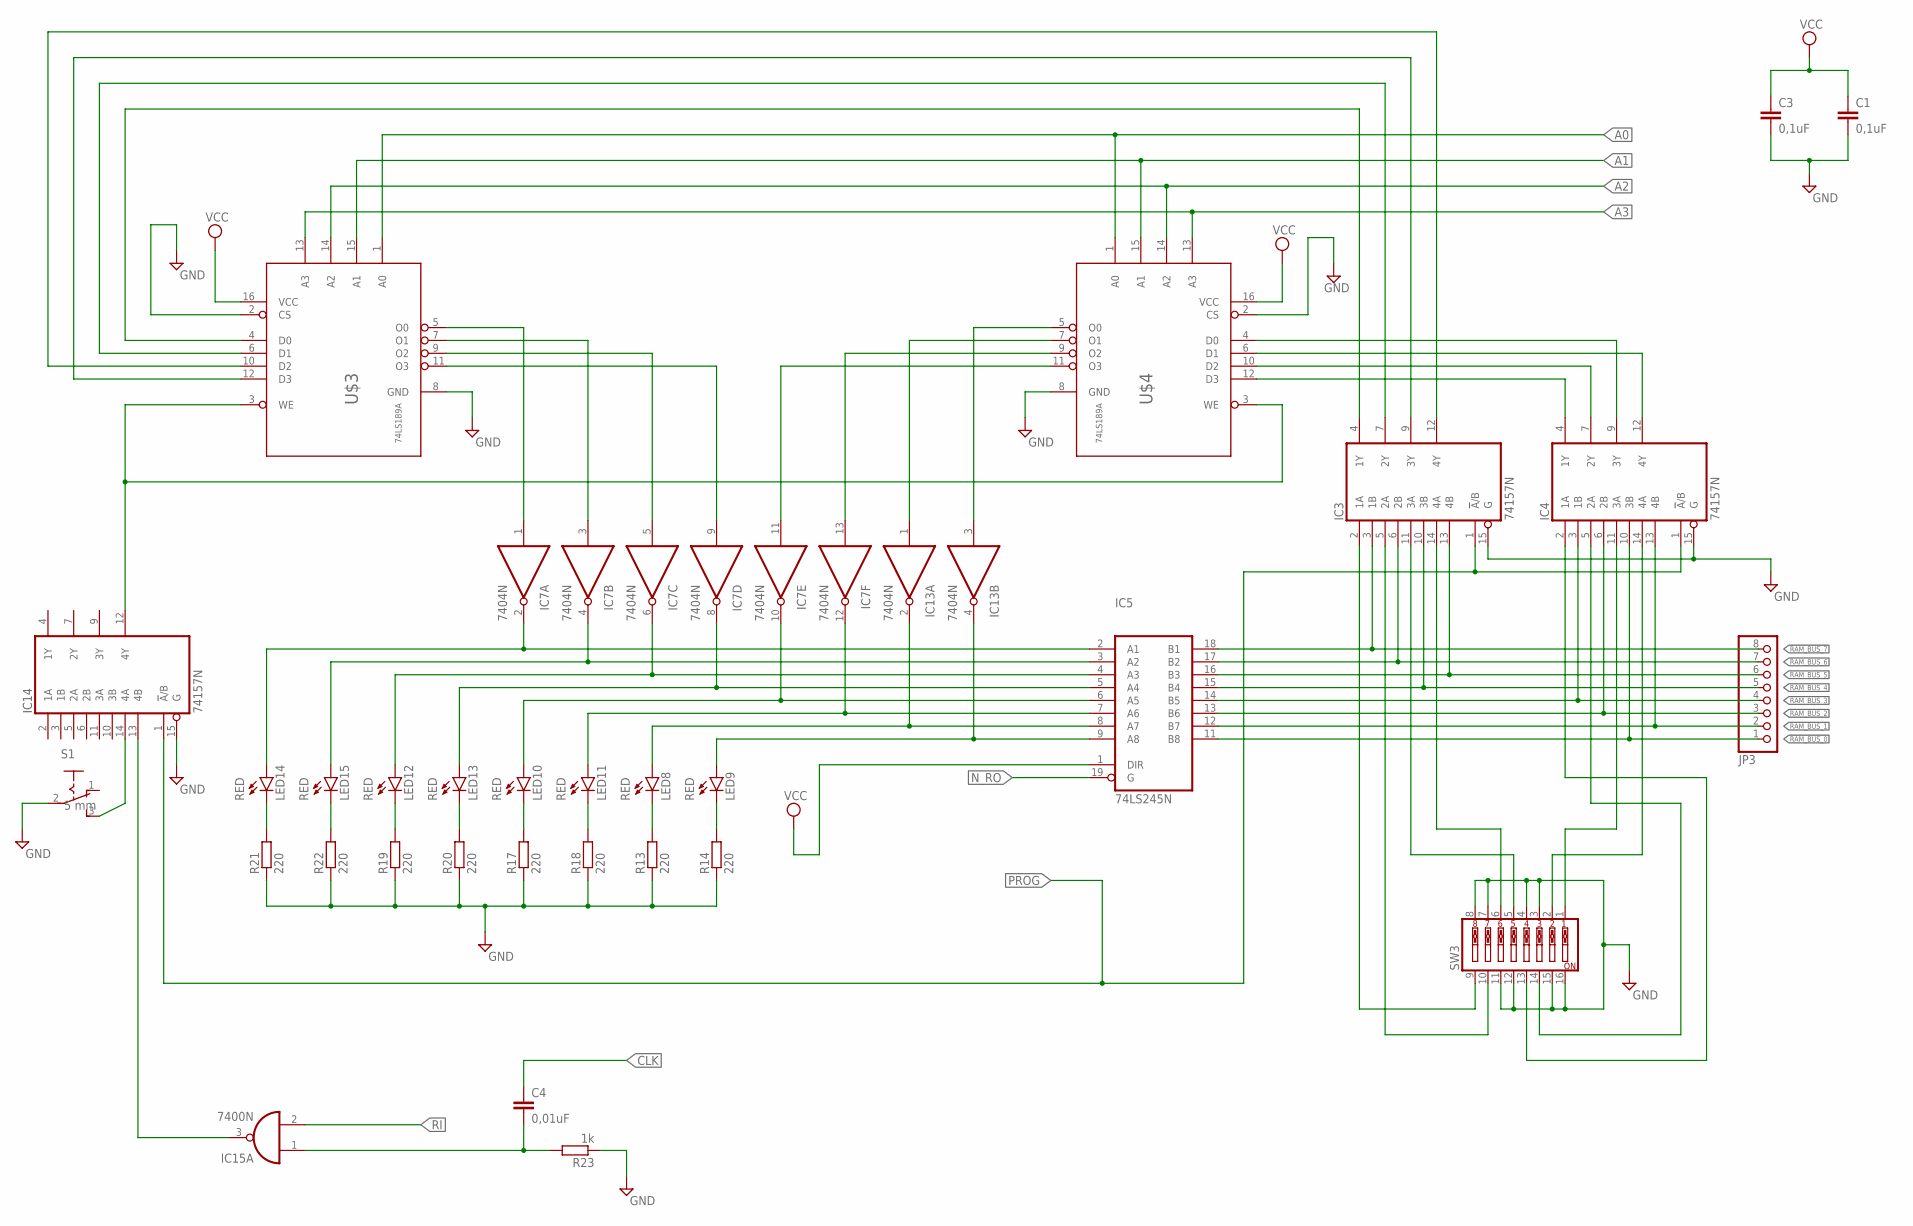
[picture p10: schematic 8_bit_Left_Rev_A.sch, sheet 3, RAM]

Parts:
C1, C3: 0,1uF; C025-030X050
C4: 0,01uF; C025-030X050
IC3, IC4, IC14: 74157N; DIL16
IC5: 74LS245N; DIL20
IC7, IC13: 7404N; DIL14
IC15: 7400N; DIL14
JP3: PINHD-1X8; 1X08
LED8, LED9, LED10, LED11, LED12, LED13, LED14, LED15: RED; LED5MM
R13, R14, R17, R18, R19, R20, R21, R22: 220; 0207/10
R23: 1k; 0207/10
S1: 5 mm; 255SB
SW3: EDG-08
U$3, U$4: 74LS189A; 74LS189

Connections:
A0: U$3.1 (A0), U$4.1 (A0); also elsewhere on the board
A1: U$3.15 (A1), U$4.15 (A1); also elsewhere on the board
A2: U$3.14 (A2), U$4.14 (A2); also elsewhere on the board
A3: U$3.13 (A3), U$4.13 (A3); also elsewhere on the board
CLK: C4.1; also elsewhere on the board
GND: C1.2, C3.2, IC3.8 (GND), IC3.15 (G), IC4.8 (GND), IC4.15 (G), IC5.10 (GND), IC7.7 (GND), IC13.7 (GND), IC14.8 (GND), IC14.15 (G), IC15.7 (GND), R13.1, R14.1, R17.1, R18.1, R19.1, R20.1, R21.1, R22.1, R23.1, S1.2, SW3.3, SW3.4, SW3.7, SW3.8, SW3.11, SW3.12, SW3.15, SW3.16, U$3.2 (CS), U$3.8 (GND), U$4.2 (CS), U$4.8 (GND); also elsewhere on the board
GND5: LED8.K (C), R13.2
GND6: LED9.K (C), R14.2
GND7: LED10.K (C), R17.2
GND8: LED11.K (C), R18.2
GND9: LED12.K (C), R19.2
GND10: LED13.K (C), R20.2
GND11: LED14.K (C), R21.2
GND12: LED15.K (C), R22.2
unnamed: IC3.4 (1Y), U$3.4 (D0)
unnamed: IC3.7 (2Y), U$3.6 (D1)
unnamed: IC3.9 (3Y), U$3.12 (D3)
unnamed: IC3.12 (4Y), U$3.10 (D2)
unnamed: IC14.12 (4Y), U$3.3 (WE), U$4.3 (WE)
unnamed: IC13.3 (I), U$4.5 (O0)
unnamed: IC13.1 (I), U$4.7 (O1)
unnamed: IC7.13 (I), U$4.9 (O2)
unnamed: IC7.11 (I), U$4.11 (O3)
unnamed: IC7.1 (I), U$3.5 (O0)
unnamed: IC7.3 (I), U$3.7 (O1)
unnamed: IC7.5 (I), U$3.9 (O2)
unnamed: IC7.9 (I), U$3.11 (O3)
unnamed: IC5.2 (A1), IC7.2 (O), LED14.A
unnamed: IC5.3 (A2), IC7.4 (O), LED15.A
unnamed: IC5.4 (A3), IC7.6 (O), LED12.A
unnamed: IC5.5 (A4), IC7.8 (O), LED13.A
unnamed: IC5.6 (A5), IC7.10 (O), LED10.A
unnamed: IC5.7 (A6), IC7.12 (O), LED11.A
unnamed: IC5.8 (A7), IC13.2 (O), LED8.A
unnamed: IC5.9 (A8), IC13.4 (O), LED9.A
unnamed: IC14.14 (4A), S1.3 (S)
unnamed: IC14.13 (4B), IC15.3 (O)
unnamed: C4.2, IC15.1 (I0), R23.2
unnamed: IC3.2 (1A), SW3.9
unnamed: IC3.5 (2A), SW3.10
unnamed: IC3.11 (3A), SW3.5
unnamed: IC3.14 (4A), SW3.6
unnamed: IC4.14 (4A), SW3.2
unnamed: IC4.5 (2A), SW3.14
unnamed: IC4.11 (3A), SW3.1
unnamed: IC4.2 (1A), SW3.13
unnamed: IC4.9 (3Y), U$4.4 (D0)
unnamed: IC4.4 (1Y), U$4.12 (D3)
unnamed: IC4.7 (2Y), U$4.10 (D2)
unnamed: IC4.12 (4Y), U$4.6 (D1)
N_RO: IC5.19 (G); also elsewhere on the board
PROG: IC3.1 (!A!/B), IC4.1 (!A!/B), IC14.1 (!A!/B); also elsewhere on the board
RAM_BUS_0: IC4.10 (3B), IC5.11 (B8), JP3.1
RAM_BUS_1: IC4.13 (4B), IC5.12 (B7), JP3.2
RAM_BUS_2: IC4.6 (2B), IC5.13 (B6), JP3.3
RAM_BUS_3: IC4.3 (1B), IC5.14 (B5), JP3.4
RAM_BUS_4: IC3.10 (3B), IC5.15 (B4), JP3.5
RAM_BUS_5: IC3.13 (4B), IC5.16 (B3), JP3.6
RAM_BUS_6: IC3.6 (2B), IC5.17 (B2), JP3.7
RAM_BUS_7: IC3.3 (1B), IC5.18 (B1), JP3.8
RI: IC15.2 (I1); also elsewhere on the board
VCC: C1.1, C3.1, IC3.16 (VCC), IC4.16 (VCC), IC5.1 (DIR), IC5.20 (VCC), IC7.14 (VCC), IC13.14 (VCC), IC14.16 (VCC), IC15.14 (VCC), U$3.16 (VCC), U$4.16 (VCC); also elsewhere on the board

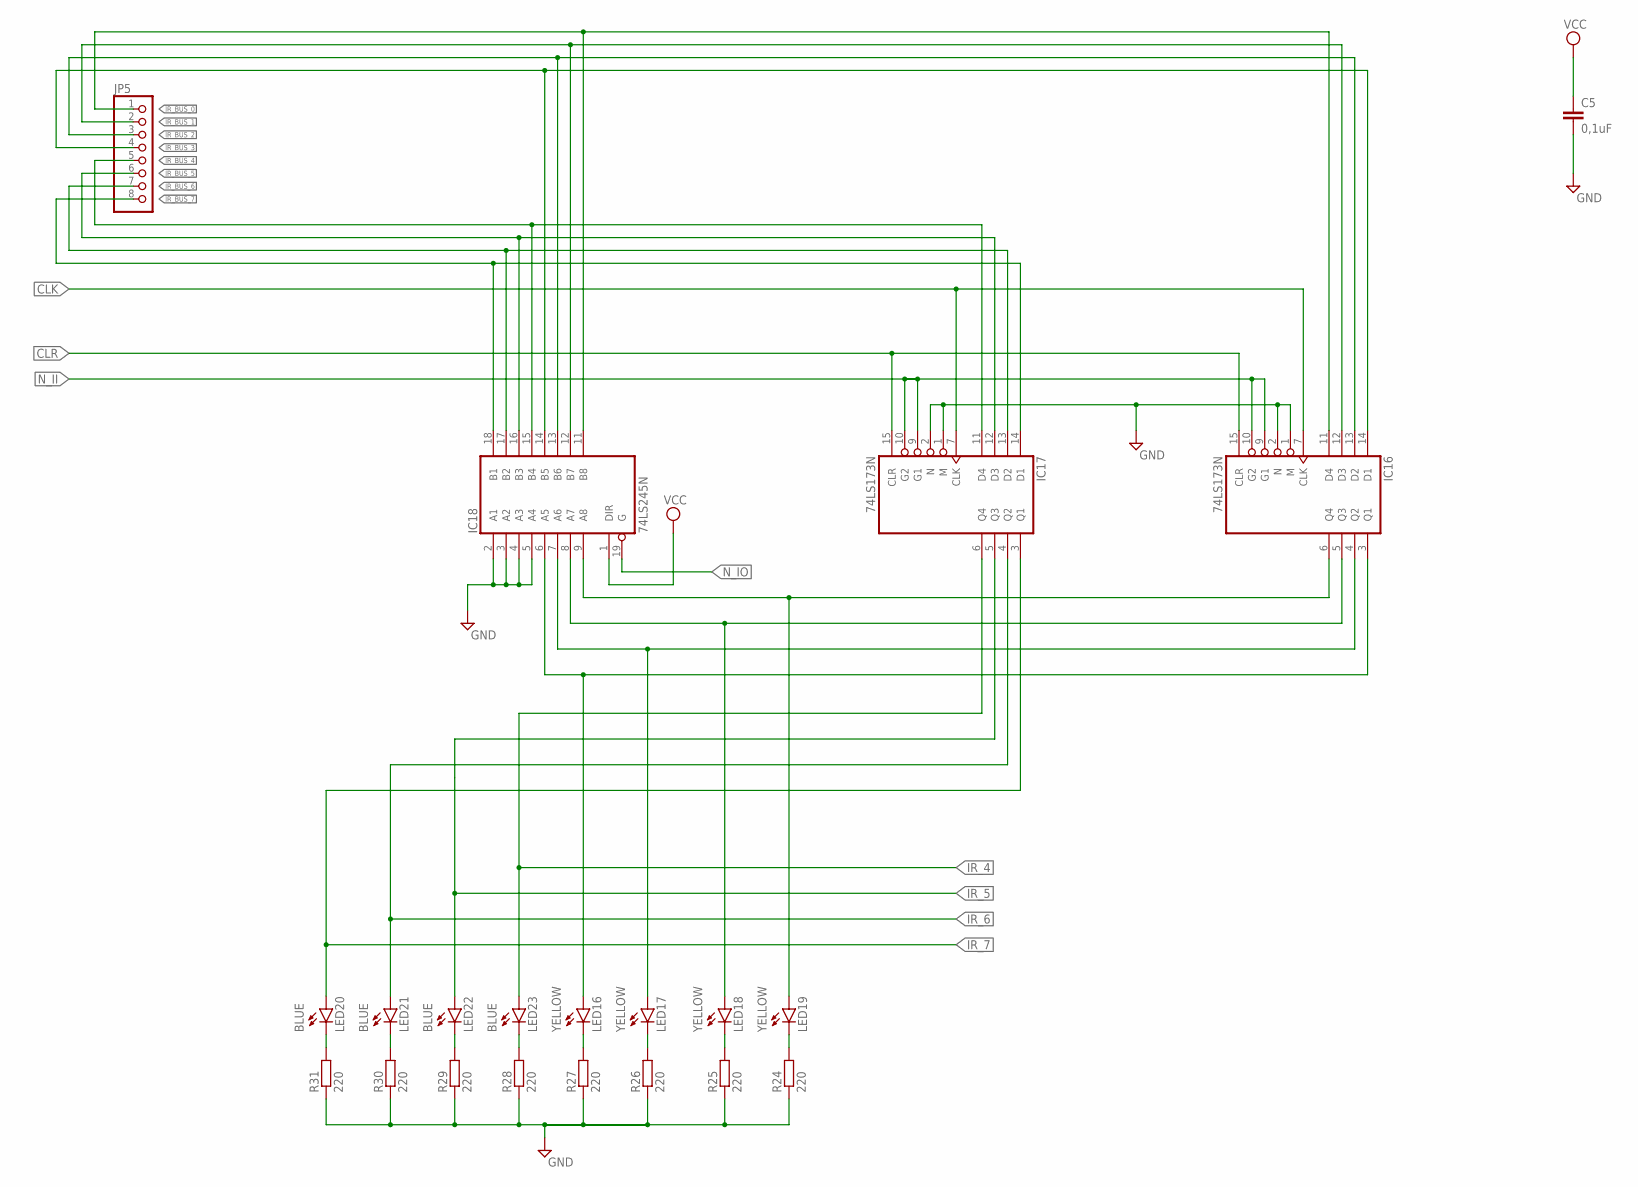
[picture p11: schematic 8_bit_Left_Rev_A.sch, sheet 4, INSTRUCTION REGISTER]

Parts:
C5: 0,1uF; C025-030X050
IC16, IC17: 74LS173N; DIL16
IC18: 74LS245N; DIL20
JP5: PINHD-1X8; 1X08
LED16, LED17, LED18, LED19: YELLOW; LED5MM
LED20, LED21, LED22, LED23: BLUE; LED5MM
R24, R25, R26, R27, R28, R29, R30, R31: 220; 0207/10

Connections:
CLK: IC16.7 (CLK), IC17.7 (CLK); also elsewhere on the board
CLR: IC16.15 (CLR), IC17.15 (CLR); also elsewhere on the board
GND: C5.2, IC16.1 (M), IC16.2 (N), IC16.8 (GND), IC17.1 (M), IC17.2 (N), IC17.8 (GND), IC18.2 (A1), IC18.3 (A2), IC18.4 (A3), IC18.5 (A4), IC18.10 (GND), R24.1, R25.1, R26.1, R27.1, R28.1, R29.1, R30.1, R31.1; also elsewhere on the board
GND15: LED19.K (C), R24.2
GND16: LED18.K (C), R25.2
GND17: LED17.K (C), R26.2
GND18: LED16.K (C), R27.2
GND19: LED23.K (C), R28.2
GND20: LED22.K (C), R29.2
GND21: LED21.K (C), R30.2
GND22: LED20.K (C), R31.2
IR_4: IC17.6 (Q4), LED23.A; also elsewhere on the board
IR_5: IC17.5 (Q3), LED22.A; also elsewhere on the board
IR_6: IC17.4 (Q2), LED21.A; also elsewhere on the board
IR_7: IC17.3 (Q1), LED20.A; also elsewhere on the board
IR_BUS_0: IC16.11 (D4), IC18.11 (B8), JP5.1
IR_BUS_1: IC16.12 (D3), IC18.12 (B7), JP5.2
IR_BUS_2: IC16.13 (D2), IC18.13 (B6), JP5.3
IR_BUS_3: IC16.14 (D1), IC18.14 (B5), JP5.4
IR_BUS_4: IC17.11 (D4), IC18.15 (B4), JP5.5
IR_BUS_5: IC17.12 (D3), IC18.16 (B3), JP5.6
IR_BUS_6: IC17.13 (D2), IC18.17 (B2), JP5.7
IR_BUS_7: IC17.14 (D1), IC18.18 (B1), JP5.8
unnamed: IC16.6 (Q4), IC18.9 (A8), LED19.A
unnamed: IC16.5 (Q3), IC18.8 (A7), LED18.A
unnamed: IC16.4 (Q2), IC18.7 (A6), LED17.A
unnamed: IC16.3 (Q1), IC18.6 (A5), LED16.A
N_II: IC16.9 (G1), IC16.10 (G2), IC17.9 (G1), IC17.10 (G2); also elsewhere on the board
N_IO: IC18.19 (G); also elsewhere on the board
VCC: C5.1, IC16.16 (VCC), IC17.16 (VCC), IC18.1 (DIR), IC18.20 (VCC); also elsewhere on the board

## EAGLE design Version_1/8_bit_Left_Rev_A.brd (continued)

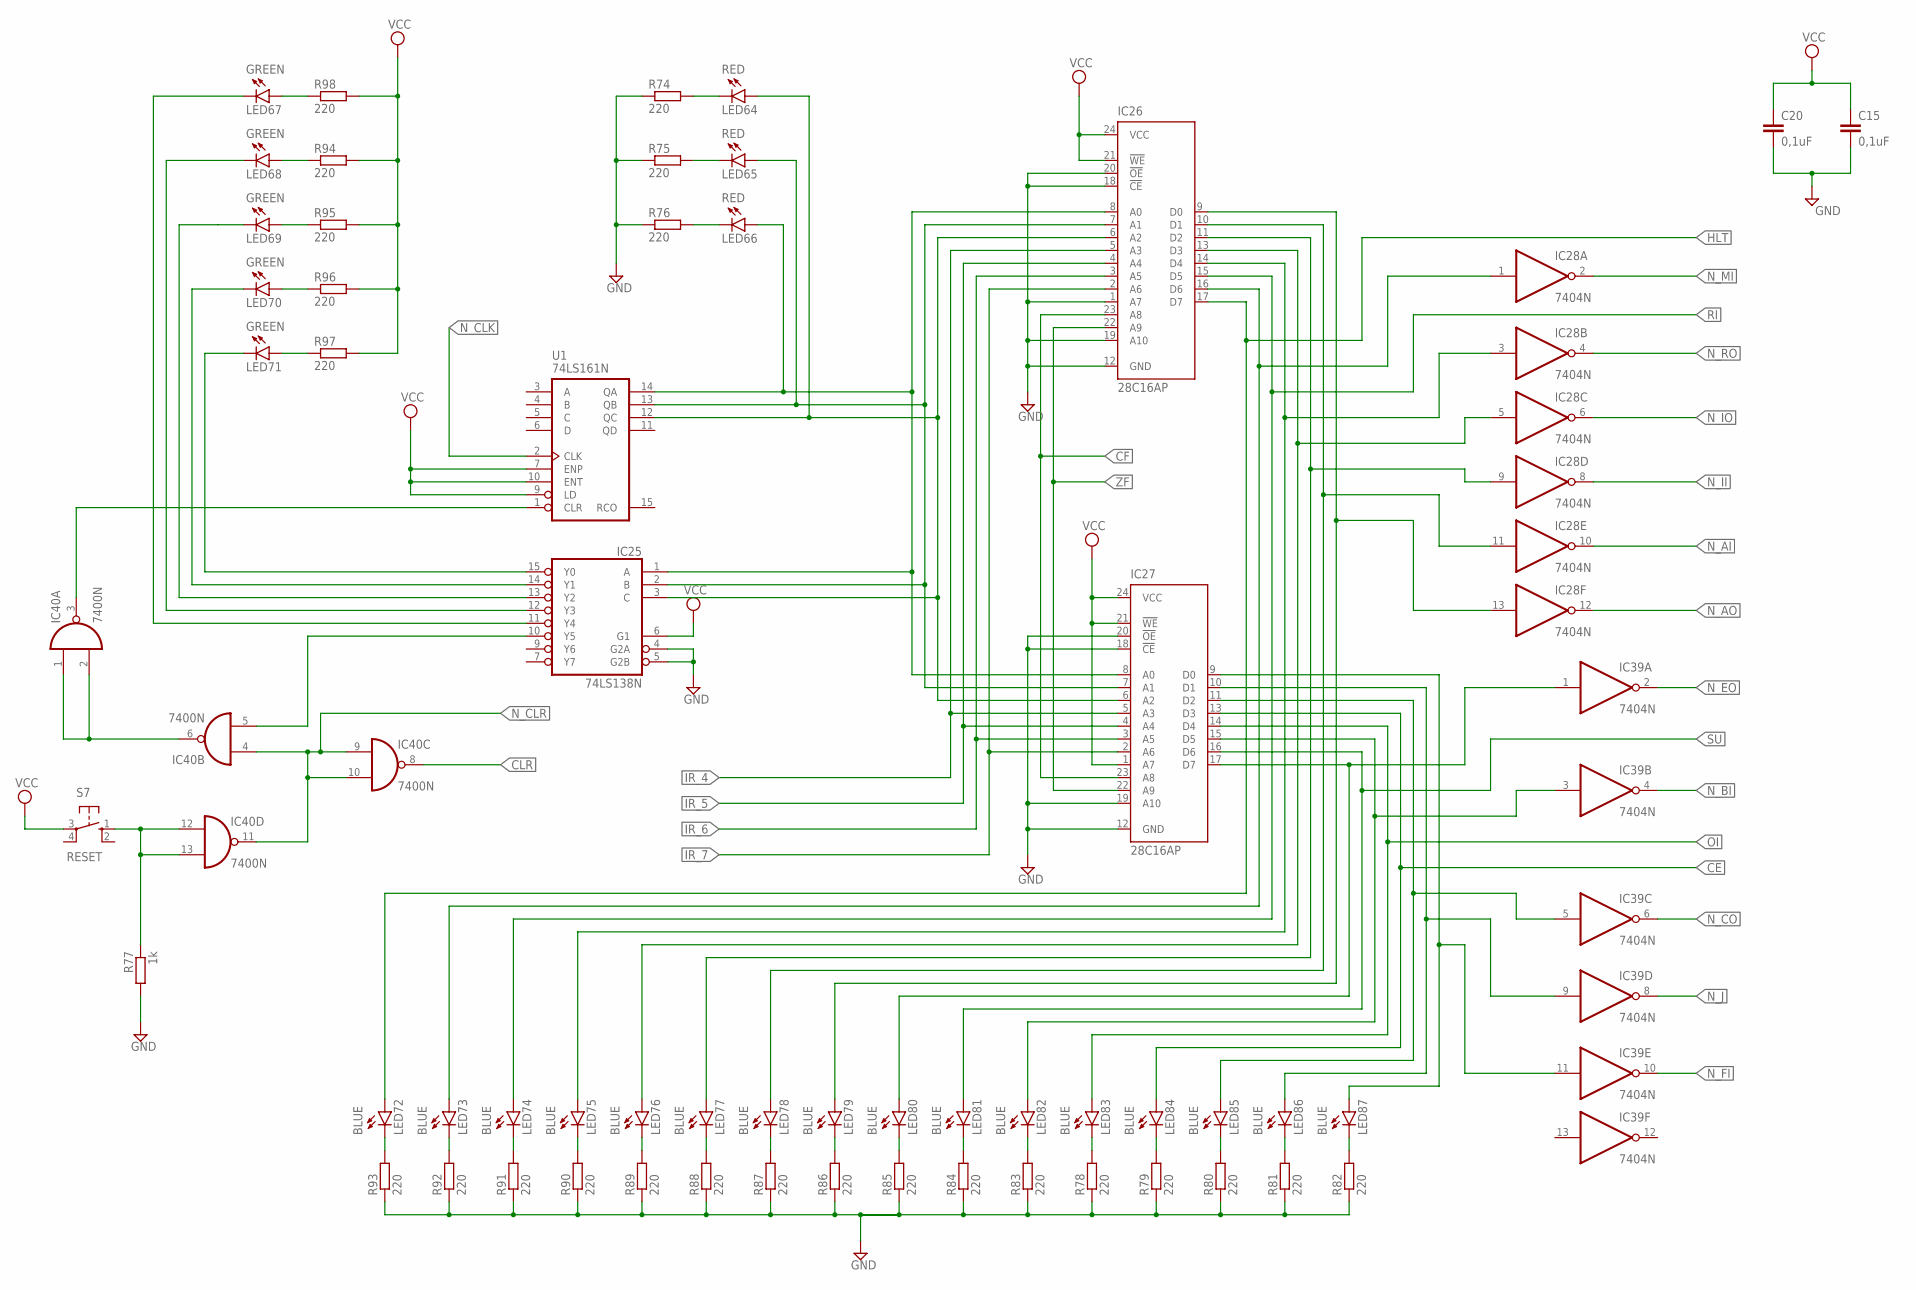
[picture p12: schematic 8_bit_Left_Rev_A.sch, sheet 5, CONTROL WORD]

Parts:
C15, C20: 0,1uF; C025-030X050
IC25: 74LS138N; DIL16
IC26, IC27: 28C16AP; DIL24-6
IC28, IC39: 7404N; DIL14
IC40: 7400N; DIL14
LED64, LED65, LED66: RED; LED5MM
LED67, LED68, LED69, LED70, LED71: GREEN; LED5MM
LED72, LED73, LED74, LED75, LED76, LED77, LED78, LED79, LED80, LED81, LED82, LED83, LED84, LED85, LED86, LED87: BLUE; LED5MM
R74, R75, R76, R78, R79, R80, R81, R82, R83, R84, R85, R86, R87, R88, R89, R90, R91, R92, R93, R94, R95, R96, R97, R98: 220; 0207/10
R77: 1k; 0207/10
S7: RESET; B3F-10XX
U1: 74LS161N; DIL16

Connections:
ASD1: IC25.10 (Y5), IC40.5 (I1)
CE: IC27.13 (D3), LED84.A; also elsewhere on the board
CF: IC26.23 (A8), IC27.23 (A8); also elsewhere on the board
CLK4: IC25.1 (A), IC26.8 (A0), IC27.8 (A0), LED66.A, U1.14 (QA)
CLK5: IC25.2 (B), IC26.7 (A1), IC27.7 (A1), LED65.A, U1.13 (QB)
CLK6: IC25.3 (C), IC26.6 (A2), IC27.6 (A2), LED64.A, U1.12 (QC)
CLR: IC40.8 (O); also elsewhere on the board
GND: C15.2, C20.2, IC25.4 (G2A), IC25.5 (G2B), IC25.8 (GND), IC26.1 (A7), IC26.12 (GND), IC26.18 (!CE), IC26.19 (A10), IC26.20 (!OE), IC27.12 (GND), IC27.18 (!CE), IC27.19 (A10), IC27.20 (!OE), IC28.7 (GND), IC39.7 (GND), IC40.7 (GND), R74.1, R75.1, R76.1, R77.2, R78.1, R79.1, R80.1, R81.1, R82.1, R83.1, R84.1, R85.1, R86.1, R87.1, R88.1, R89.1, R90.1, R91.1, R92.1, R93.1, U1.8 (GND); also elsewhere on the board
GND61: LED64.K (C), R74.2
GND62: LED65.K (C), R75.2
GND63: LED66.K (C), R76.2
GND64: IC25.12 (Y3), LED68.K (C)
GND65: IC25.13 (Y2), LED69.K (C)
GND66: IC25.14 (Y1), LED70.K (C)
GND67: IC25.15 (Y0), LED71.K (C)
GND68: IC25.11 (Y4), LED67.K (C)
GND69: LED83.K (C), R78.2
GND70: LED84.K (C), R79.2
GND71: LED85.K (C), R80.2
GND72: LED86.K (C), R81.2
GND73: LED87.K (C), R82.2
GND74: LED82.K (C), R83.2
GND75: LED81.K (C), R84.2
GND76: LED80.K (C), R85.2
GND77: LED79.K (C), R86.2
GND78: LED78.K (C), R87.2
GND79: LED77.K (C), R88.2
GND80: LED76.K (C), R89.2
GND81: LED75.K (C), R90.2
GND82: LED74.K (C), R91.2
GND83: LED73.K (C), R92.2
GND84: LED72.K (C), R93.2
HLT: IC26.17 (D7), LED72.A; also elsewhere on the board
IR_4: IC26.5 (A3), IC27.5 (A3); also elsewhere on the board
IR_5: IC26.4 (A4), IC27.4 (A4); also elsewhere on the board
IR_6: IC26.3 (A5), IC27.3 (A5); also elsewhere on the board
IR_7: IC26.2 (A6), IC27.2 (A6); also elsewhere on the board
unnamed: IC40.1 (I0), IC40.2 (I1), IC40.6 (O)
unnamed: IC40.3 (O), U1.1 (CLR)
unnamed: IC40.12 (I0), IC40.13 (I1), R77.1, S7.1 (S)
unnamed: IC26.14 (D4), IC28.3 (I), LED75.A
unnamed: IC26.13 (D3), IC28.5 (I), LED76.A
unnamed: IC26.11 (D2), IC28.9 (I), LED77.A
unnamed: IC26.10 (D1), IC28.11 (I), LED78.A
unnamed: IC26.9 (D0), IC28.13 (I), LED79.A
unnamed: IC27.17 (D7), IC39.1 (I), LED80.A
unnamed: IC27.15 (D5), IC39.3 (I), LED82.A
unnamed: IC27.11 (D2), IC39.5 (I), LED85.A
unnamed: IC27.10 (D1), IC39.9 (I), LED86.A
unnamed: IC27.9 (D0), IC39.11 (I), LED87.A
unnamed: LED69.A, R95.1
unnamed: LED68.A, R94.1
unnamed: LED70.A, R96.1
unnamed: LED67.A, R98.1
unnamed: LED71.A, R97.1
N_AI: IC28.10 (O); also elsewhere on the board
N_AO: IC28.12 (O); also elsewhere on the board
N_BI: IC39.4 (O); also elsewhere on the board
N_CLK: U1.2 (CLK); also elsewhere on the board
N_CLR: IC40.4 (I0), IC40.9 (I0), IC40.10 (I1), IC40.11 (O); also elsewhere on the board
N_CO: IC39.6 (O); also elsewhere on the board
N_EO: IC39.2 (O); also elsewhere on the board
N_FI: IC39.10 (O); also elsewhere on the board
N_II: IC28.8 (O); also elsewhere on the board
N_IO: IC28.6 (O); also elsewhere on the board
N_J: IC39.8 (O); also elsewhere on the board
N_MI: IC28.2 (O); also elsewhere on the board
N_RO: IC28.4 (O); also elsewhere on the board
OI: IC27.14 (D4), LED83.A; also elsewhere on the board
QWER1: IC26.16 (D6), IC28.1 (I), LED73.A
RI: IC26.15 (D5), LED74.A; also elsewhere on the board
SU: IC27.16 (D6), LED81.A; also elsewhere on the board
VCC: C15.1, C20.1, IC25.6 (G1), IC25.16 (VCC), IC26.21 (!WE), IC26.24 (VCC), IC27.1 (A7), IC27.21 (!WE), IC27.24 (VCC), IC28.14 (VCC), IC39.14 (VCC), IC40.14 (VCC), R94.2, R95.2, R96.2, R97.2, R98.2, S7.3, U1.7 (ENP), U1.9 (LD), U1.10 (ENT), U1.16 (VCC); also elsewhere on the board
ZF: IC26.22 (A9), IC27.22 (A9); also elsewhere on the board

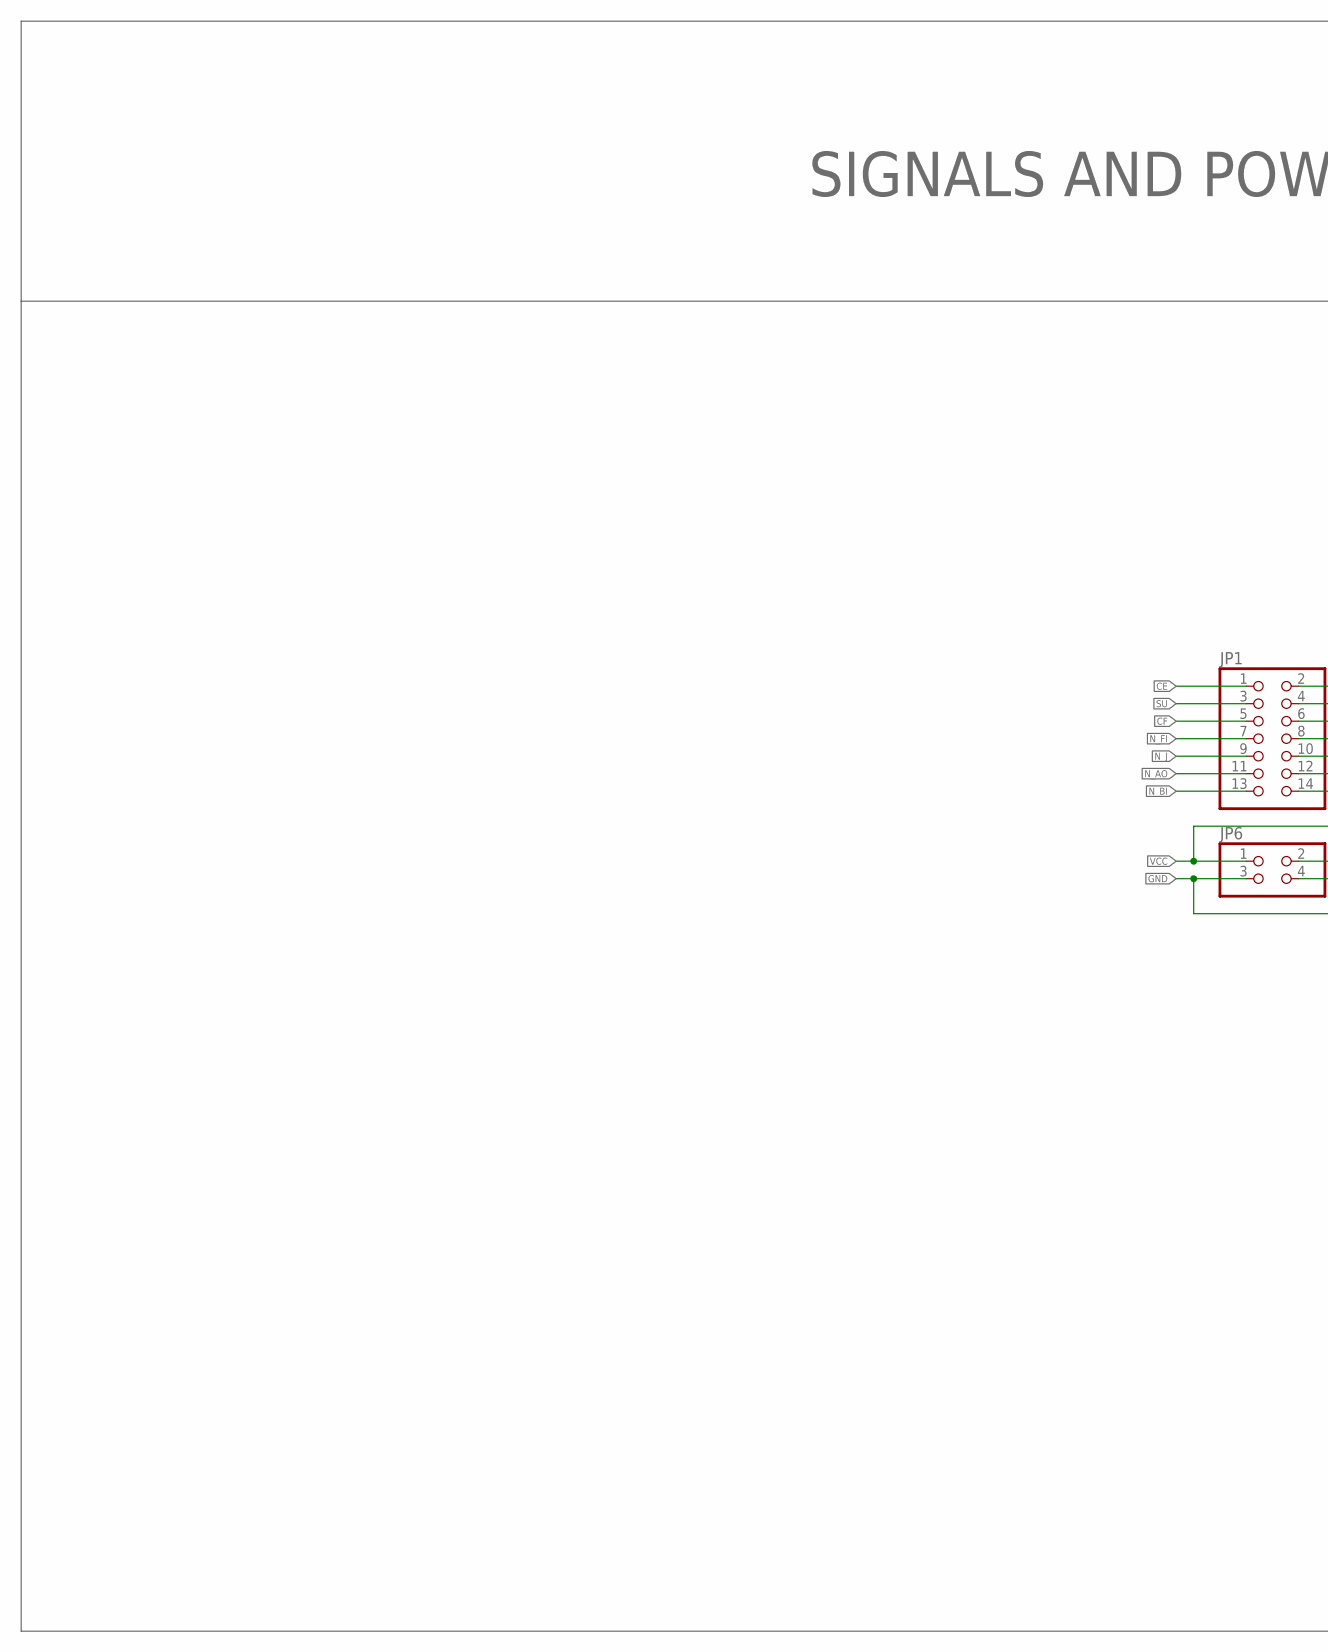
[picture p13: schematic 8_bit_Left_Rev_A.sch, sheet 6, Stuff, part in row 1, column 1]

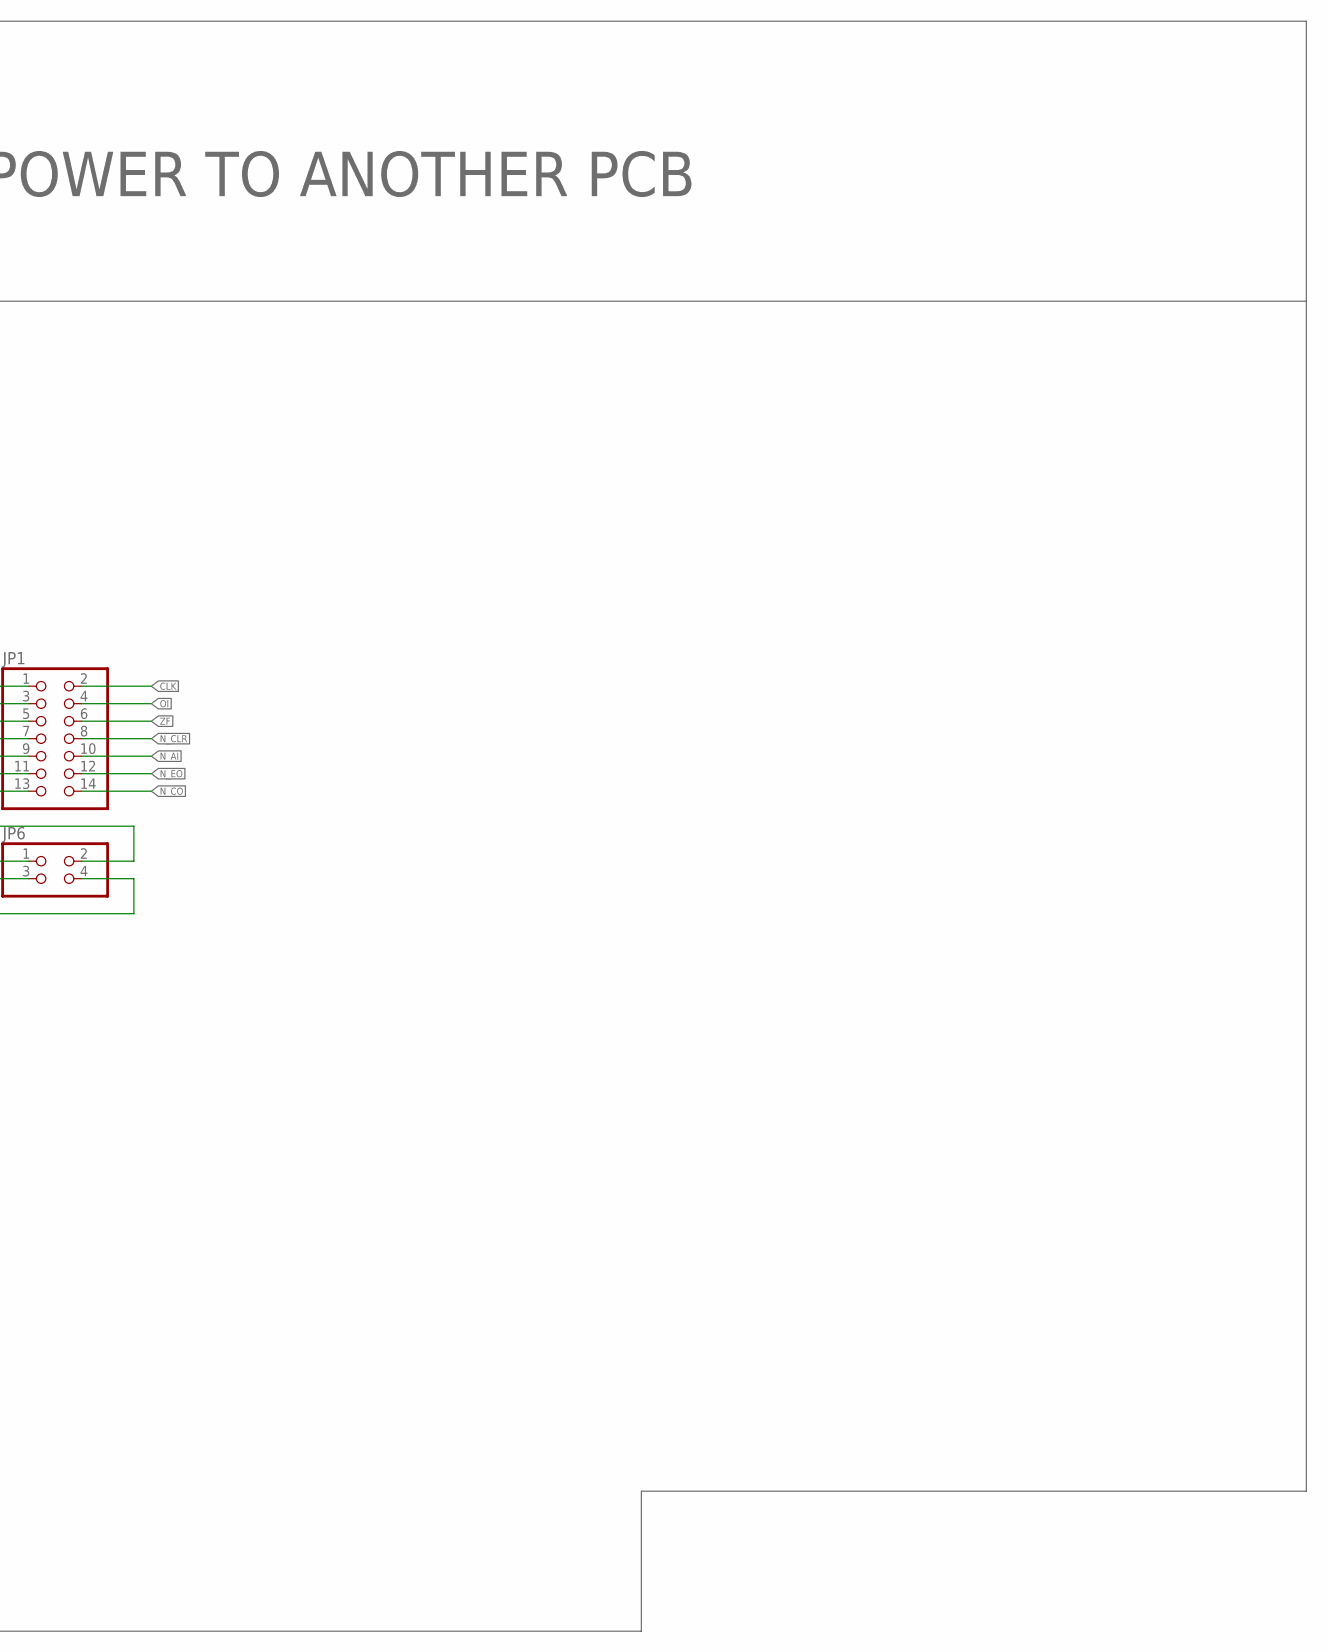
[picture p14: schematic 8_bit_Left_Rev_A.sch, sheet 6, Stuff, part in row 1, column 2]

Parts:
JP1: PINHD-2X7; 2X07
JP6: PINHD-2X2; 2X02

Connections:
CE: JP1.1; also elsewhere on the board
CF: JP1.5; also elsewhere on the board
CLK: JP1.2; also elsewhere on the board
GND: JP6.3, JP6.4; also elsewhere on the board
N_AI: JP1.10; also elsewhere on the board
N_AO: JP1.11; also elsewhere on the board
N_BI: JP1.13; also elsewhere on the board
N_CLR: JP1.8; also elsewhere on the board
N_CO: JP1.14; also elsewhere on the board
N_EO: JP1.12; also elsewhere on the board
N_FI: JP1.7; also elsewhere on the board
N_J: JP1.9; also elsewhere on the board
OI: JP1.4; also elsewhere on the board
SU: JP1.3; also elsewhere on the board
VCC: JP6.1, JP6.2; also elsewhere on the board
ZF: JP1.6; also elsewhere on the board

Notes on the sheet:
SIGNALS AND POWER TO ANOTHER PCB

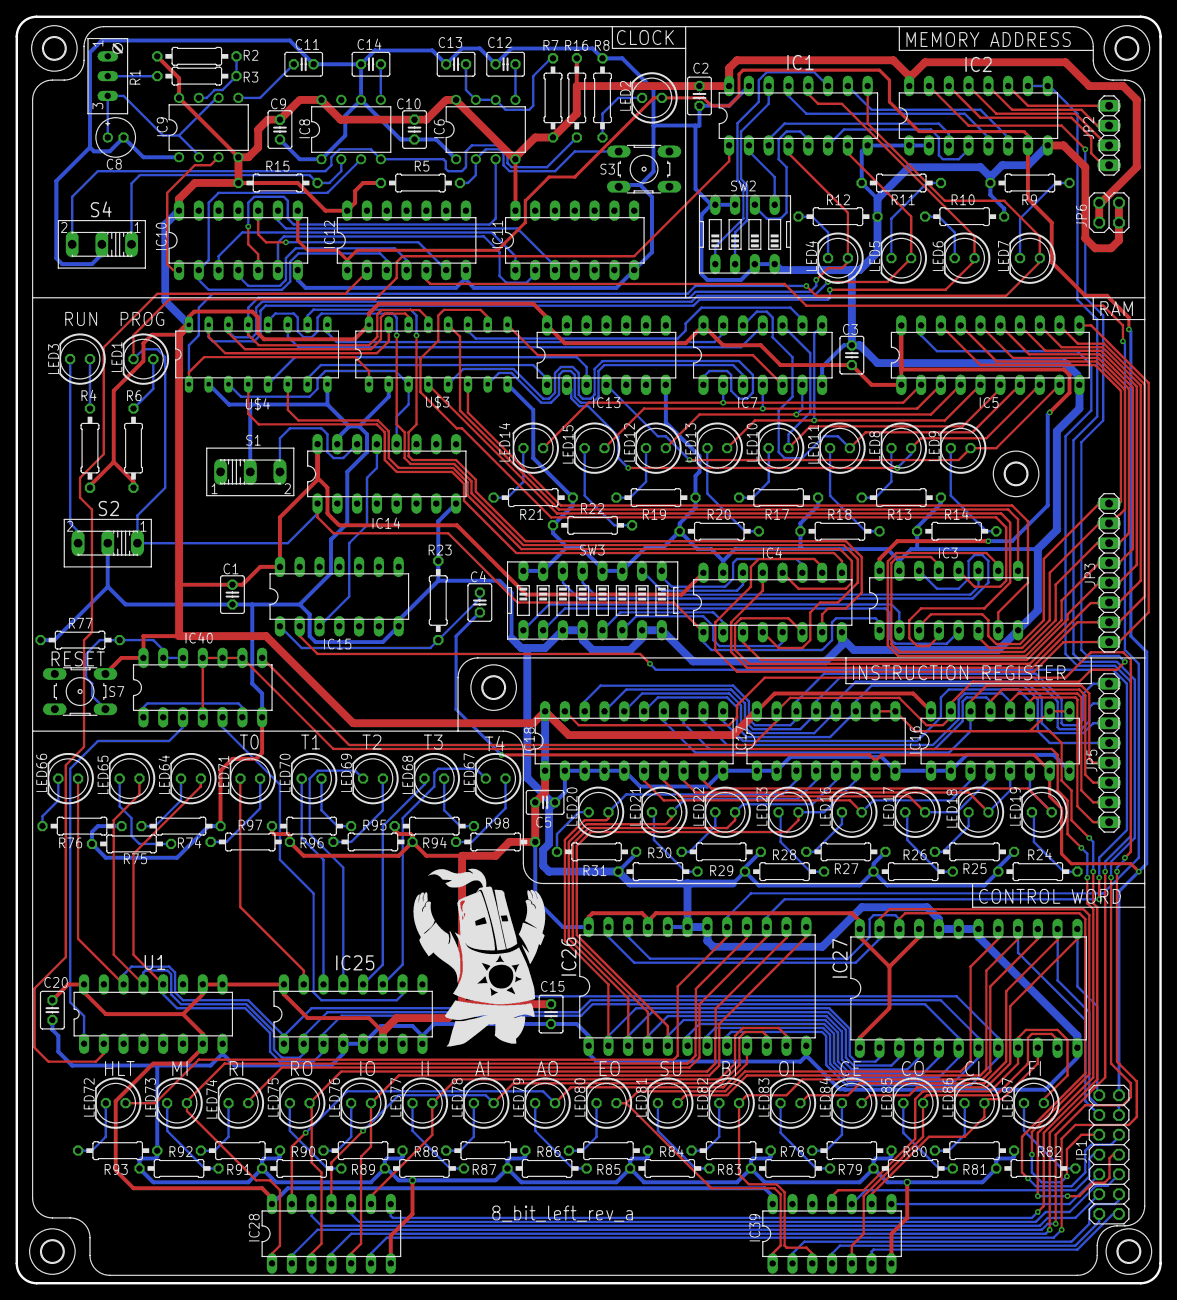
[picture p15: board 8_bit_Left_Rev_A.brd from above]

Board: 2 copper layers, 146.8 x 162.6 mm, 164 parts (1 on the bottom side), 190 nets.

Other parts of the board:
H1, H2, H3, H4, H5, H6: MOUNT-HOLE2.8; 2,8
U$1: MUELLTONNE_10.00
U$2: SOLAIRE

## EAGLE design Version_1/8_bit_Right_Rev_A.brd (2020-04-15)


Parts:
C1: 0,1uF; C025-030X050
IC1: 74LS245N; DIL20
JP2: PINHD-1X4; 1X04
LED1, LED2, LED3, LED4: GREEN; LED5MM
R1, R2, R3, R4: 220; 0207/10
U2: 74LS161N; DIL16

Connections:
CE: U2.7 (ENP), U2.10 (ENT); also elsewhere on the board
CLK: U2.2 (CLK); also elsewhere on the board
GND: C1.2, IC1.1 (DIR), IC1.10 (GND), R1.2, R2.2, R3.2, R4.2, U2.8 (GND); also elsewhere on the board
unnamed: LED1.K (C), R4.1
unnamed: LED2.K (C), R1.1
unnamed: LED3.K (C), R2.1
unnamed: LED4.K (C), R3.1
unnamed: IC1.11 (B8), LED4.A, U2.14 (QA)
unnamed: IC1.12 (B7), LED3.A, U2.13 (QB)
unnamed: IC1.13 (B6), LED2.A, U2.12 (QC)
unnamed: IC1.14 (B5), LED1.A, U2.11 (QD)
N_CLR: U2.1 (CLR); also elsewhere on the board
N_CO: IC1.19 (G); also elsewhere on the board
N_J: U2.9 (LD); also elsewhere on the board
PC_BUS_0: IC1.9 (A8), JP2.1, U2.3 (A)
PC_BUS_1: IC1.8 (A7), JP2.2, U2.4 (B)
PC_BUS_2: IC1.7 (A6), JP2.3, U2.5 (C)
PC_BUS_3: IC1.6 (A5), JP2.4, U2.6 (D)
VCC: C1.1, IC1.20 (VCC), U2.16 (VCC); also elsewhere on the board


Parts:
C2: 0,1uF; C025-030X050
IC2, IC3: 74LS173N; DIL16
IC4: 74LS245N; DIL20
JP3: PINHD-1X8; 1X08
LED5, LED6, LED7, LED8, LED9, LED10, LED11, LED12: RED; LED5MM
R5, R6, R7, R8, R9, R10, R11, R12: 220; 0207/10

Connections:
A_0: IC2.6 (Q4), IC4.9 (A8), LED8.A; also elsewhere on the board
A_1: IC2.5 (Q3), IC4.8 (A7), LED7.A; also elsewhere on the board
A_2: IC2.4 (Q2), IC4.7 (A6), LED6.A; also elsewhere on the board
A_3: IC2.3 (Q1), IC4.6 (A5), LED5.A; also elsewhere on the board
A_4: IC3.6 (Q4), IC4.5 (A4), LED12.A; also elsewhere on the board
A_5: IC3.5 (Q3), IC4.4 (A3), LED11.A; also elsewhere on the board
A_6: IC3.4 (Q2), IC4.3 (A2), LED10.A; also elsewhere on the board
A_7: IC3.3 (Q1), IC4.2 (A1), LED9.A; also elsewhere on the board
A_BUS_0: IC2.11 (D4), IC4.11 (B8), JP3.1
A_BUS_1: IC2.12 (D3), IC4.12 (B7), JP3.2
A_BUS_2: IC2.13 (D2), IC4.13 (B6), JP3.3
A_BUS_3: IC2.14 (D1), IC4.14 (B5), JP3.4
A_BUS_4: IC3.11 (D4), IC4.15 (B4), JP3.5
A_BUS_5: IC3.12 (D3), IC4.16 (B3), JP3.6
A_BUS_6: IC3.13 (D2), IC4.17 (B2), JP3.7
A_BUS_7: IC3.14 (D1), IC4.18 (B1), JP3.8
CLK: IC2.7 (CLK), IC3.7 (CLK); also elsewhere on the board
CLR: IC2.15 (CLR), IC3.15 (CLR); also elsewhere on the board
GND: C2.2, IC2.1 (M), IC2.2 (N), IC2.8 (GND), IC3.1 (M), IC3.2 (N), IC3.8 (GND), IC4.10 (GND), R5.1, R6.1, R7.1, R8.1, R9.1, R10.1, R11.1, R12.1; also elsewhere on the board
GND1: LED8.K (C), R5.2
GND2: LED7.K (C), R6.2
GND3: LED6.K (C), R7.2
GND4: LED5.K (C), R8.2
GND5: LED12.K (C), R9.2
GND6: LED11.K (C), R10.2
GND7: LED10.K (C), R11.2
GND8: LED9.K (C), R12.2
N_AI: IC2.9 (G1), IC2.10 (G2), IC3.9 (G1), IC3.10 (G2); also elsewhere on the board
N_AO: IC4.19 (G); also elsewhere on the board
VCC: C2.1, IC2.16 (VCC), IC3.16 (VCC), IC4.1 (DIR), IC4.20 (VCC); also elsewhere on the board


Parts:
C3, C4: 0,1uF; C025-030X050
IC5, IC6: 74S283N; DIL16
IC7: 74LS245N; DIL20
IC8: 74LS173N; DIL16
IC9, IC10: 7486N; DIL14
IC11: 7402N; DIL14
IC12: 74S08N; DIL14
JP5: PINHD-1X8; 1X08
LED13, LED14, LED15, LED16, LED17, LED18, LED19, LED20: RED; LED5MM
LED21, LED22: GREEN; LED5MM
R13, R14, R15, R16, R17, R18, R19, R20, R21, R22: 220; 0207/10

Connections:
ALU_BUS_0: IC7.11 (B8), JP5.1
ALU_BUS_1: IC7.12 (B7), JP5.2
ALU_BUS_2: IC7.13 (B6), JP5.3
ALU_BUS_3: IC7.14 (B5), JP5.4
ALU_BUS_4: IC7.15 (B4), JP5.5
ALU_BUS_5: IC7.16 (B3), JP5.6
ALU_BUS_6: IC7.17 (B2), JP5.7
ALU_BUS_7: IC7.18 (B1), JP5.8
A_0: IC5.5 (A1); also elsewhere on the board
A_1: IC5.3 (A2); also elsewhere on the board
A_2: IC5.14 (A3); also elsewhere on the board
A_3: IC5.12 (A4); also elsewhere on the board
A_4: IC6.5 (A1); also elsewhere on the board
A_5: IC6.3 (A2); also elsewhere on the board
A_6: IC6.14 (A3); also elsewhere on the board
A_7: IC6.12 (A4); also elsewhere on the board
B_0: IC10.12 (I0); also elsewhere on the board
B_1: IC10.9 (I0); also elsewhere on the board
B_2: IC10.4 (I0); also elsewhere on the board
B_3: IC10.1 (I0); also elsewhere on the board
B_4: IC9.12 (I0); also elsewhere on the board
B_5: IC9.9 (I0); also elsewhere on the board
B_6: IC9.4 (I0); also elsewhere on the board
B_7: IC9.1 (I0); also elsewhere on the board
CF: IC8.3 (Q1), LED21.A; also elsewhere on the board
CLK: IC8.7 (CLK); also elsewhere on the board
CLR: IC8.15 (CLR); also elsewhere on the board
GND: C3.2, C4.2, IC5.8 (GND), IC6.8 (GND), IC7.10 (GND), IC8.1 (M), IC8.2 (N), IC8.8 (GND), IC9.7 (GND), IC10.7 (GND), IC11.7 (GND), IC12.7 (GND), R13.2, R14.2, R15.2, R16.2, R17.2, R18.2, R19.2, R20.2, R21.2, R22.2; also elsewhere on the board
unnamed: IC5.9 (C4), IC6.7 (C0)
unnamed: IC6.11 (B4), IC9.3 (O)
unnamed: IC6.15 (B3), IC9.6 (O)
unnamed: IC6.2 (B2), IC9.8 (O)
unnamed: IC6.6 (B1), IC9.11 (O)
unnamed: IC5.11 (B4), IC10.3 (O)
unnamed: IC5.15 (B3), IC10.6 (O)
unnamed: IC5.2 (B2), IC10.8 (O)
unnamed: IC5.6 (B1), IC10.11 (O)
unnamed: LED13.K (C), R13.1
unnamed: LED14.K (C), R14.1
unnamed: LED15.K (C), R15.1
unnamed: LED16.K (C), R16.1
unnamed: LED17.K (C), R17.1
unnamed: LED18.K (C), R18.1
unnamed: LED19.K (C), R19.1
unnamed: LED20.K (C), R20.1
unnamed: IC6.10 (S4), IC7.2 (A1), IC11.3 (I1), LED16.A
unnamed: IC6.13 (S3), IC7.3 (A2), IC11.2 (I0), LED13.A
unnamed: IC6.1 (S2), IC7.4 (A3), IC11.6 (I1), LED14.A
unnamed: IC6.4 (S1), IC7.5 (A4), IC11.5 (I0), LED15.A
unnamed: IC5.10 (S4), IC7.6 (A5), IC11.9 (I1), LED17.A
unnamed: IC5.13 (S3), IC7.7 (A6), IC11.8 (I0), LED18.A
unnamed: IC5.1 (S2), IC7.8 (A7), IC11.12 (I1), LED19.A
unnamed: IC5.4 (S1), IC7.9 (A8), IC11.11 (I0), LED20.A
unnamed: IC11.1 (O), IC12.10 (I1)
unnamed: IC11.4 (O), IC12.9 (I0)
unnamed: IC11.10 (O), IC12.5 (I1)
unnamed: IC11.13 (O), IC12.4 (I0)
unnamed: IC12.1 (I0), IC12.6 (O)
unnamed: IC12.2 (I1), IC12.8 (O)
unnamed: IC8.13 (D2), IC12.3 (O)
unnamed: IC6.9 (C4), IC8.14 (D1)
unnamed: LED21.K (C), R21.1
unnamed: LED22.K (C), R22.1
N_EO: IC7.19 (G); also elsewhere on the board
N_FI: IC8.9 (G1), IC8.10 (G2); also elsewhere on the board
SU: IC5.7 (C0), IC9.2 (I1), IC9.5 (I1), IC9.10 (I1), IC9.13 (I1), IC10.2 (I1), IC10.5 (I1), IC10.10 (I1), IC10.13 (I1); also elsewhere on the board
VCC: C3.1, C4.1, IC5.16 (VCC), IC6.16 (VCC), IC7.1 (DIR), IC7.20 (VCC), IC8.16 (VCC), IC9.14 (VCC), IC10.14 (VCC), IC11.14 (VCC), IC12.14 (VCC); also elsewhere on the board
ZF: IC8.4 (Q2), LED22.A; also elsewhere on the board

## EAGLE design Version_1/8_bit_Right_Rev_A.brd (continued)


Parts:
C5: 0,1uF; C025-030X050
IC13, IC14: 74LS173N; DIL16
IC15: 74LS245N; DIL20
JP7: PINHD-1X8; 1X08
LED23, LED24, LED25, LED26, LED27, LED28, LED29, LED30: RED; LED5MM
R23, R24, R25, R26, R27, R28, R29, R30: 220; 0207/10

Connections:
B_0: IC13.6 (Q4), IC15.9 (A8), LED26.A; also elsewhere on the board
B_1: IC13.5 (Q3), IC15.8 (A7), LED25.A; also elsewhere on the board
B_2: IC13.4 (Q2), IC15.7 (A6), LED24.A; also elsewhere on the board
B_3: IC13.3 (Q1), IC15.6 (A5), LED23.A; also elsewhere on the board
B_4: IC14.6 (Q4), IC15.5 (A4), LED30.A; also elsewhere on the board
B_5: IC14.5 (Q3), IC15.4 (A3), LED29.A; also elsewhere on the board
B_6: IC14.4 (Q2), IC15.3 (A2), LED28.A; also elsewhere on the board
B_7: IC14.3 (Q1), IC15.2 (A1), LED27.A; also elsewhere on the board
B_BUS_0: IC13.11 (D4), IC15.11 (B8), JP7.1
B_BUS_1: IC13.12 (D3), IC15.12 (B7), JP7.2
B_BUS_2: IC13.13 (D2), IC15.13 (B6), JP7.3
B_BUS_3: IC13.14 (D1), IC15.14 (B5), JP7.4
B_BUS_4: IC14.11 (D4), IC15.15 (B4), JP7.5
B_BUS_5: IC14.12 (D3), IC15.16 (B3), JP7.6
B_BUS_6: IC14.13 (D2), IC15.17 (B2), JP7.7
B_BUS_7: IC14.14 (D1), IC15.18 (B1), JP7.8
CLK: IC13.7 (CLK), IC14.7 (CLK); also elsewhere on the board
CLR: IC13.15 (CLR), IC14.15 (CLR); also elsewhere on the board
GND: C5.2, IC13.1 (M), IC13.2 (N), IC13.8 (GND), IC14.1 (M), IC14.2 (N), IC14.8 (GND), IC15.10 (GND), R23.1, R24.1, R25.1, R26.1, R27.1, R28.1, R29.1, R30.1; also elsewhere on the board
GND9: LED26.K (C), R23.2
GND10: LED25.K (C), R24.2
GND11: LED24.K (C), R25.2
GND12: LED23.K (C), R26.2
GND13: LED30.K (C), R27.2
GND14: LED29.K (C), R28.2
GND15: LED28.K (C), R29.2
GND16: LED27.K (C), R30.2
N_BI: IC13.9 (G1), IC13.10 (G2), IC14.9 (G1), IC14.10 (G2); also elsewhere on the board
N_BO: IC15.19 (G)
VCC: C5.1, IC13.16 (VCC), IC14.16 (VCC), IC15.1 (DIR), IC15.20 (VCC); also elsewhere on the board


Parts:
C6, C7: 0,1uF; C025-030X050
C8, C9: 0,01uF; C025-030X050
DIS5, DIS6, DIS7, DIS8: HD-H103; HDSP-M
IC16: 74LS139N; DIL16
IC17: 28C16AP; DIL24-6
IC18: 7476N; DIL16
IC19: LM555N; DIL08
IC20: 74273N; DIL20
IC21: 74LS08N; DIL14
JP4: PINHD-1X8; 1X08
R31: 1k; 0207/10
R32: 100k; 0207/10
R33: 10k; 0207/10
S1: 5 mm; 255SB

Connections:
CLK: IC21.2 (I1); also elsewhere on the board
GND: C6.2, C7.2, C8.2, C9.2, IC16.1 (G), IC16.8 (GND), IC17.12 (GND), IC17.18 (!CE), IC17.20 (!OE), IC18.13 (GND), IC19.1 (GND), IC20.10 (GND), IC21.7 (GND), R33.1; also elsewhere on the board
unnamed: IC17.8 (A0), IC20.2 (Q1)
unnamed: IC17.7 (A1), IC20.5 (Q2)
unnamed: IC17.6 (A2), IC20.6 (Q3)
unnamed: IC17.5 (A3), IC20.9 (Q4)
unnamed: IC17.4 (A4), IC20.12 (Q5)
unnamed: IC17.3 (A5), IC20.15 (Q6)
unnamed: IC17.2 (A6), IC20.16 (Q7)
unnamed: IC17.1 (A7), IC20.19 (Q8)
unnamed: DIS5.5 (DP), DIS6.5 (DP), DIS7.5 (DP), DIS8.5 (DP), IC17.17 (D7)
unnamed: DIS5.7 (A), DIS6.7 (A), DIS7.7 (A), DIS8.7 (A), IC17.16 (D6)
unnamed: DIS5.6 (B), DIS6.6 (B), DIS7.6 (B), DIS8.6 (B), IC17.15 (D5)
unnamed: DIS5.4 (C), DIS6.4 (C), DIS7.4 (C), DIS8.4 (C), IC17.14 (D4)
unnamed: DIS5.2 (D), DIS6.2 (D), DIS7.2 (D), DIS8.2 (D), IC17.13 (D3)
unnamed: DIS5.1 (E), DIS6.1 (E), DIS7.1 (E), DIS8.1 (E), IC17.11 (D2)
unnamed: DIS5.9 (F), DIS6.9 (F), DIS7.9 (F), DIS8.9 (F), IC17.10 (D1)
unnamed: DIS5.10 (G), DIS6.10 (G), DIS7.10 (G), DIS8.10 (G), IC17.9 (D0)
unnamed: DIS5.3 (CC), DIS5.8 (CC), IC16.7 (Y3)
unnamed: DIS6.3 (CC), DIS6.8 (CC), IC16.6 (Y2)
unnamed: DIS7.3 (CC), DIS7.8 (CC), IC16.5 (Y1)
unnamed: DIS8.3 (CC), DIS8.8 (CC), IC16.4 (Y0)
unnamed: IC16.3 (B), IC17.22 (A9), IC18.10 (!Q)
unnamed: IC16.2 (A), IC17.23 (A8), IC18.6 (CLK), IC18.14 (!Q)
unnamed: IC18.1 (CLK), IC19.3 (Q)
unnamed: IC19.7 (DIS), R31.1, R32.2
unnamed: C8.1, IC19.2 (TR), IC19.6 (THR), R32.1
unnamed: C9.1, IC19.5 (CV)
unnamed: IC20.11 (CLK), IC21.3 (O)
unnamed: IC17.19 (A10), S1.2
unnamed: R33.2, S1.1 (O)
N_CLR: IC20.1 (CLR); also elsewhere on the board
OI: IC21.1 (I0); also elsewhere on the board
OUT_BUS_0: IC20.3 (D1), JP4.1
OUT_BUS_1: IC20.4 (D2), JP4.2
OUT_BUS_2: IC20.7 (D3), JP4.3
OUT_BUS_3: IC20.8 (D4), JP4.4
OUT_BUS_4: IC20.13 (D5), JP4.5
OUT_BUS_5: IC20.14 (D6), JP4.6
OUT_BUS_6: IC20.17 (D7), JP4.7
OUT_BUS_7: IC20.18 (D8), JP4.8
VCC: C6.1, C7.1, IC16.16 (VCC), IC17.21 (!WE), IC17.24 (VCC), IC18.2 (PRE), IC18.3 (CLR), IC18.4 (J), IC18.5 (VCC), IC18.7 (PRE), IC18.8 (CLR), IC18.9 (J), IC18.12 (K), IC18.16 (K), IC19.8 (V+), IC20.20 (VCC), IC21.14 (VCC), R31.2, S1.3 (S); also elsewhere on the board



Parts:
D1: BZX55; DO35Z10
H1, H2, H3, H5, H6: MOUNT-HOLE2.8; 2,8
J1: DCJ0303
JP1: PINHD-2X2; 2X02
JP6: PINHD-2X7; 2X07
Q1, Q2, Q3: IRF9530; TO220BV
R34: 220; 0207/10
R35: 1k; 0207/10
S2: 255SB

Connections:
CE: JP6.1; also elsewhere on the board
CF: JP6.5; also elsewhere on the board
CLK: JP6.2; also elsewhere on the board
GND: D1.A, J1.2, J1.3, JP1.3, JP1.4, Q1.G, R35.1; also elsewhere on the board
unnamed: Q1.S, Q2.S, Q3.S, R34.2
unnamed: D1.C, Q2.G, R34.1
unnamed: Q3.D, S2.2
unnamed: Q2.D, Q3.G, R35.2
N_AI: JP6.10; also elsewhere on the board
N_AO: JP6.11; also elsewhere on the board
N_BI: JP6.13; also elsewhere on the board
N_CLR: JP6.8; also elsewhere on the board
N_CO: JP6.14; also elsewhere on the board
N_EO: JP6.12; also elsewhere on the board
N_FI: JP6.7; also elsewhere on the board
N_J: JP6.9; also elsewhere on the board
OI: JP6.4; also elsewhere on the board
SU: JP6.3; also elsewhere on the board
VCC: JP1.1, JP1.2, S2.3 (S); also elsewhere on the board
VDD: J1.1, Q1.D
ZF: JP6.6; also elsewhere on the board

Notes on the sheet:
MAIN VOLTAGE ENTRANCE
OVERVOLTAGE AND REVERSE POLARITY PROTECTION
MOUTING HOLES
SIGNALS AND POWER TO ANOTHER PCB


Board: 2 copper layers, 102.4 x 152.7 mm, 121 parts (1 on the bottom side), 162 nets.

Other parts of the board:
U$1: SOLAIRE
U$2: MUELLTONNE_10.00

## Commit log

2020-04-09 Vesrsion 1 Left part of the PC
    [8_bit_Left_Rev_A.brd, 8_bit_Left_Rev_A.sch]
2020-04-09 Version 1 Middle part of the PC
    [8_bit_Middle_Rev_A.brd, 8_bit_Middle_Rev_A.sch]
2020-04-09 Version 1 Right part of the PC
    [8_bit_Right_Rev_A.brd, 8_bit_Right_Rev_A.sch]
2020-04-10 Full BOM for 3 PCB
    [8_bit_PC_BOM .xlsx]
2020-04-10 Gerber files
2020-04-10 Improved BOM
    [8_bit_PC_BOM .xlsx]
2020-04-10 Sorterd stuff
    [8_bit_PC_BOM .xlsx]
2020-04-15 Fixed DRC problems
    [8_bit_Left_Rev_A.brd, 8_bit_Right_Rev_A.brd]
2020-04-15 Screen of the board
2020-04-15 Trash image on the other side
    [8_bit_Left_Rev_A.brd, 8_bit_Middle_Rev_A.brd]
